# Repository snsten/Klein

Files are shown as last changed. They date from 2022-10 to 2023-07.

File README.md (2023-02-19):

# Klein Keyboard

Klein keyboard is a 36 keys, columnar staggered, split keyboard named after [Felix Klein](https://en.wikipedia.org/wiki/Felix_Klein)

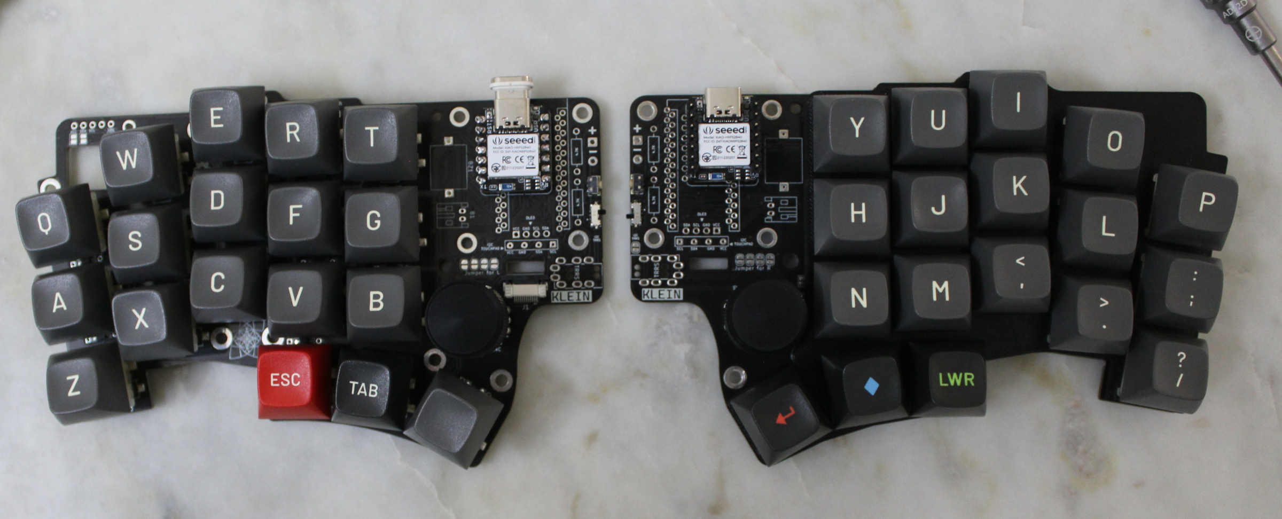
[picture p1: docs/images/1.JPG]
Klein


---

## Features

- Column Staggered
- Bluetooth compatible with power switch
- Seeed Studio XIAO-BLE / Pro Micro / nice!nano\* / KB2040 / RP2040(boards with Pro Micro pinout) compatible
- Hotswap MX and Choc switches support
- Trackpad support with FPC cable and direct wiring
- Reversible SMD and through hole diode footprint

> \* nice!nano firmware not available at the moment.

## Versions

Supports multiple options of micro controller and sensors.

| Features Supported | Microcontroller | Firmware available | Wired | Wireless |
| --- | --- | --- | ----- | --- |
| Encoder or OLED | XIAO-BLE | [Yes](https://github.com/snsten/Klein-zmk) | | Yes |
| Encoder, OLED, TouchPad, Buzzer, Haptics | Pro Micro | [Yes](https://github.com/snsten/Klein-qmk) | Yes | |
| Encoder, OLED, TouchPad, Buzzer, Haptics | KB2040/RP2040 | [Yes](https://github.com/snsten/Klein-qmk) | Yes | |
| Encoder and OLED | nice!nano | No (Planned) | | Yes |

Broadly divided in two types:

### Wireless

- Can be made with Seeed Studio XIAO-BLE
- Supports either rotary encoder or OLED
- Battery connectors JST and THT

Wireless touchpad is currently not supported in ZMK.

### Wired

- With any Pro Micro based boards
  - Can support encoders, OLED, Touchpad, Buzzer and Haptics

---

### Keyboard Images

PCB with both Choc and MX switches
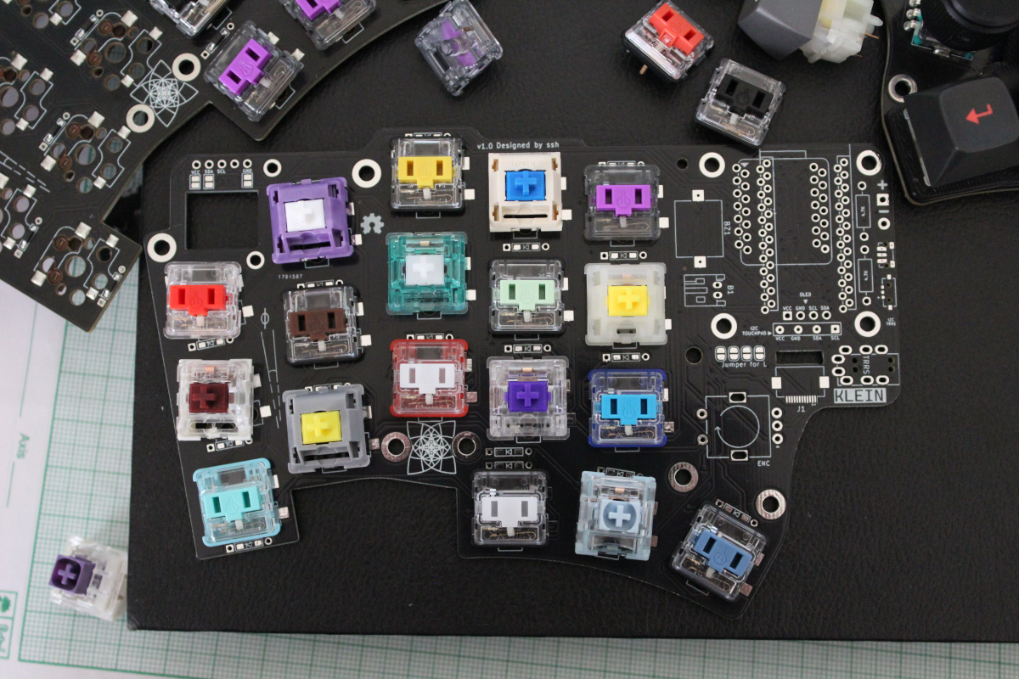
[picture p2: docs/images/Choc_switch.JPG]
Klein Choc Switches


Low Profile Choc version
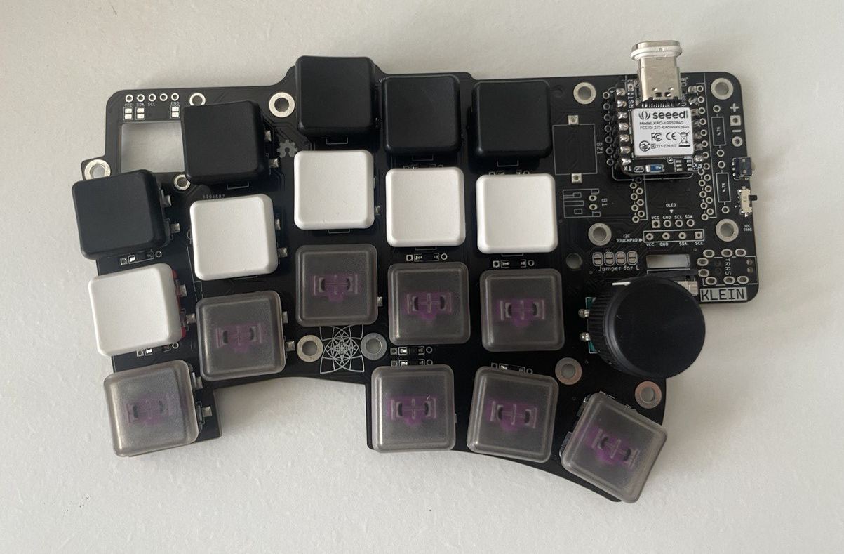
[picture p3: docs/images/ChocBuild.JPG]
Klein MX Choc Switches


MX version
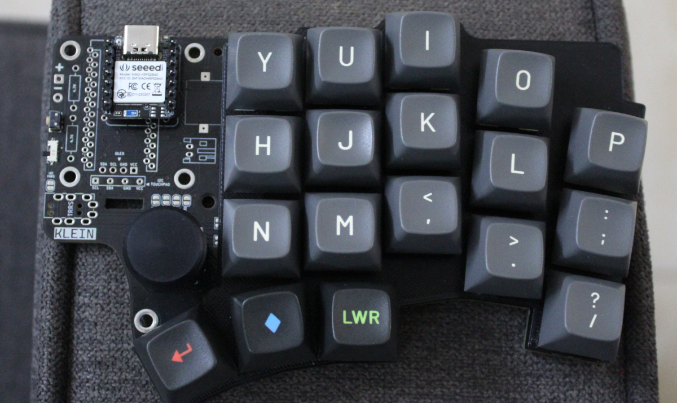
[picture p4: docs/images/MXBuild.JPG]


---

## Repo Layout and Files

```
.
├── BOM
│   ├── BOM-3235-SEEED.csv         <- BOM
│   └── ibom.html
├── Case
│   └── *.stl                      <- Case stl Files
│   └── Prototype                  <- FreeCad project files (Not tested)
│       └── SwitchPlateFR4         <- SwitchPlate PCB files (Not tested)
├── docs
│   └── images
├── Logo
├── PCB
└── README.md
```

## BOM

It is available in BOM directory as csv file and [interactive HTML BOM](https://htmlpreview.github.io/?https://github.com/snsten/Klein/blob/main/BOM/ibom.html)

## Build Guide

- Wired build [guide](https://github.com/snsten/Klein/blob/main/docs/buildguides/buildguide_wired.md)
- Wireless build [guide](https://github.com/snsten/Klein/blob/main/docs/buildguides/buildguide_wireless.md)

## Todo

- Add Build Guide
- Add Touchpad related 3D Models
- Software support for Touchpad/OLED

## Firmware

- [ZMK shield](https://github.com/snsten/Klein-zmk) for Klein with rotary encoder support.
- [QMK Firmware](https://github.com/snsten/Klein-qmk) for Pro Micro with touchpad support.

## Refrences

These projects inspired and helped in making Klein:

- [Lily58](https://github.com/kata0510/Lily58) (Hotswap Footprints)
- [Dilemma](https://github.com/Bastardkb/dilemma) (Trackpad Mount, Design)
- [KLOR](https://github.com/GEIGEIGEIST/KLOR) (Haptics Footprints, Design)
- [Claw44](https://github.com/yfuku/claw44) (Design)

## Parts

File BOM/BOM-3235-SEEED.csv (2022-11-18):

Designator | MPN/Seeed SKU | Qty | Link
D1, D2, D3, D4, D5, D6, D7, D8, D9, D10, D11, D12, D13, D14, D15, D16, D17, D18, D19 | 1N4148W | 19 | https://file.elecfans.com/web1/M00/9B/4F/o4YBAF0kaAOAOa7_AAPvYDJhMOM395.pdf?filename=1N4148W.pdf
M1 | 102010448 | 1 | https://statics3.seeedstudio.com/fusion/opl/datasheet/102010448.pdf
B1 | S2B-PH-K-S(LF)(SN) | 1 | https://file.elecfans.com/web1/M00/56/28/pIYBAFs5_uCAdW0LAAHQrBga-SA964.pdf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
S1 | SSAJ110100 | 1 | https://file.elecfans.com/web1/M00/B8/ED/o4YBAF6BmECACKjzAAnBvSqgQfU963.pdf?filename=SSAJ110100-ALPS.pdf
S16 | EC11E18244AU | 1 | https://file.elecfans.com/web1/M00/90/2D/o4YBAFzFBtCALQJ0AAlE9NU9dVE732.pdf?filename=EC11E18244AU_ALPS.pdf
H1, H2, H3, H4, H5, H6 | 326010010 | 6 | https://statics3.seeedstudio.com/fusion/opl/datasheet/326010010.pdf
U1 | 326010014 | 4 | https://statics3.seeedstudio.com/fusion/opl/datasheet/326010014.pdf
RSW1 | SKRTLAE010 | 1 | https://file.elecfans.com/web1/M00/8E/E1/o4YBAFy5PDeAGPVcAAin-c8L2b4965.pdf?filename=SKRTLAE010_ALPS.pdf
J1 | AFC07-S12FCA-00 | 1 | https://file.elecfans.com/web1/M00/86/24/o4YBAFx8f7-AXpwqAAO6FXDMfQQ684.pdf
BZ1 | AST1109MLTRQ | 1 | https://www.mouser.com/ProductDetail/Mallory-Sonalert/AST1109MLTRQ?qs=GpRChIzryBM5c7g4uet5pQ%3D%3D
J2 | PIM452 | 1 | https://www.mouser.com/ProductDetail/Pimoroni/PIM452?qs=PzGy0jfpSMsfx56IL0dynA%3D%3D
R1, R2 | MF1/4LCT52R472J | 2 | https://www.mouser.com/ProductDetail/KOA-Speer/MF1-4LCT52R472J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

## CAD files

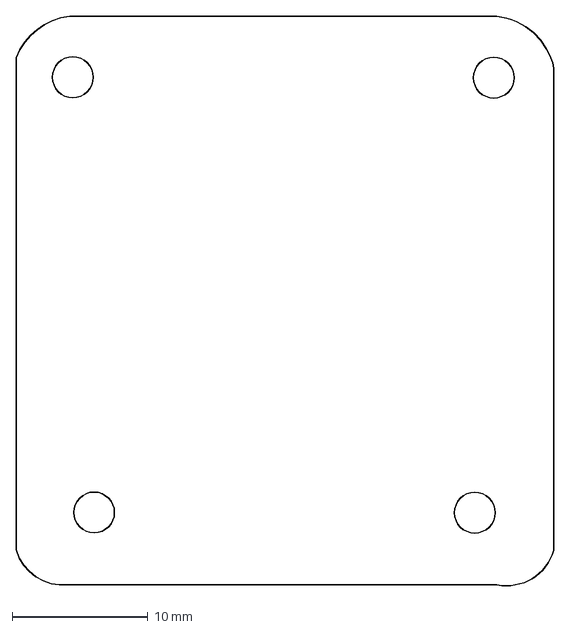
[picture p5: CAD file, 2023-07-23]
Case/coverPlate.dxf
39.5 x 42.2 mm

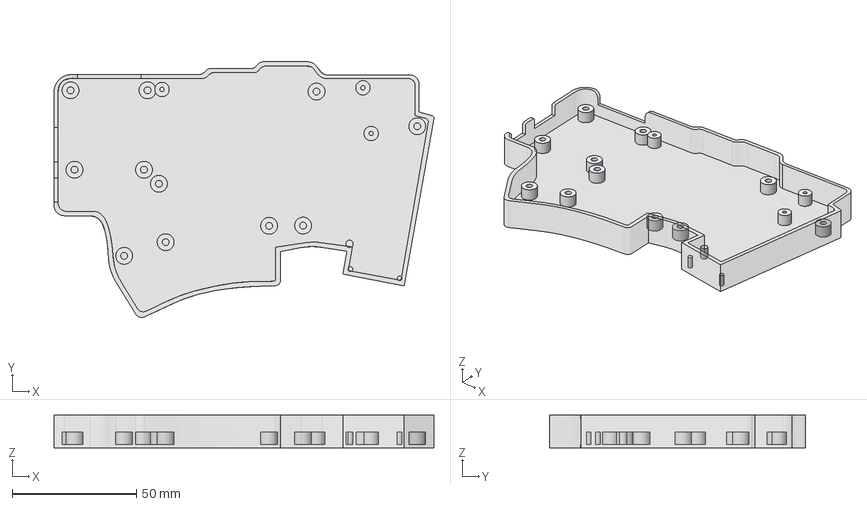
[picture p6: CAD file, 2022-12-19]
Case/Prototype/Wired_Prototype.FCStd
153.1 x 103.1 x 13.2 mm
Case
M2Hole
M2Hole001
M2Hole002
M3Hole
M3Hole001
M3Hole002
M3Hole003
M3Hole004
M3Hole005
M3Hole006
M3Hole007
M3Hole008
M3Hole009
M3Hole010
SupportCol
SupportCol001
SupportCol002

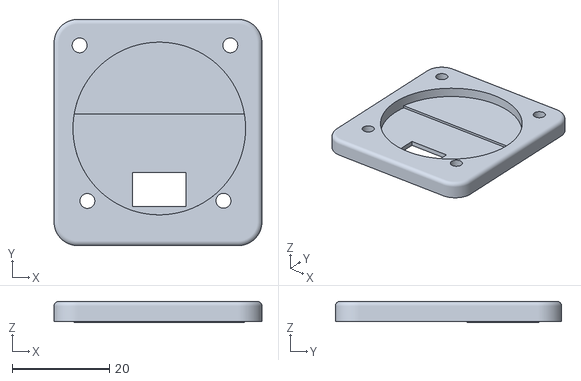
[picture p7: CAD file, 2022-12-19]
Case/TrackPadMount.stl
42.8 x 46.5 x 4.40

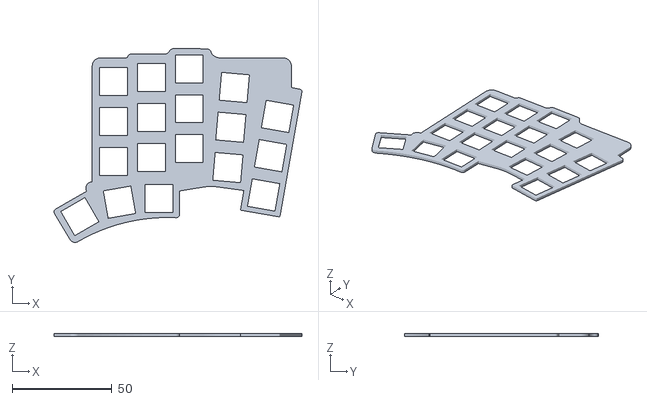
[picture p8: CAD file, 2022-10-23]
Case/Klein-switchplate.stl
124.4 x 97.2 x 1.60

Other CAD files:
Case/KleinCase-R.stl

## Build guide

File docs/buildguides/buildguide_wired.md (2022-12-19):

# Klein Wired Build Guide

---

## Table of contents

- [Overview](#overview)
- [Version Info](#version-info)
- [Parts List](#parts-list)
- [Tools Required](#tools-required)
- [Tutorials](#tutorials)
- [Build Steps](#build-steps)
  - [Diodes](#diodes)
  - [Switch Sockets](#switch-sockets)
  - [Microcontroller](#microcontroller)
  - [TRRS](#TRRS)
- [Optional](#optional)
  - [Rotary Encoders](#rotary-encoder)
  - [OLED](#oled)
  - [Trackpad](#trackpad)
  - [Reset Switch](#reset-switch)
- [Assembly](#assembly)
  - [SwitchPlate](#switchplate)
  - [Case assembly](#case-assembly)
  - [Firmware](#firmware)
- [TODO](#todo)

---

## Overview

PCB Layout and orientation

### Front / Right Side of PCB

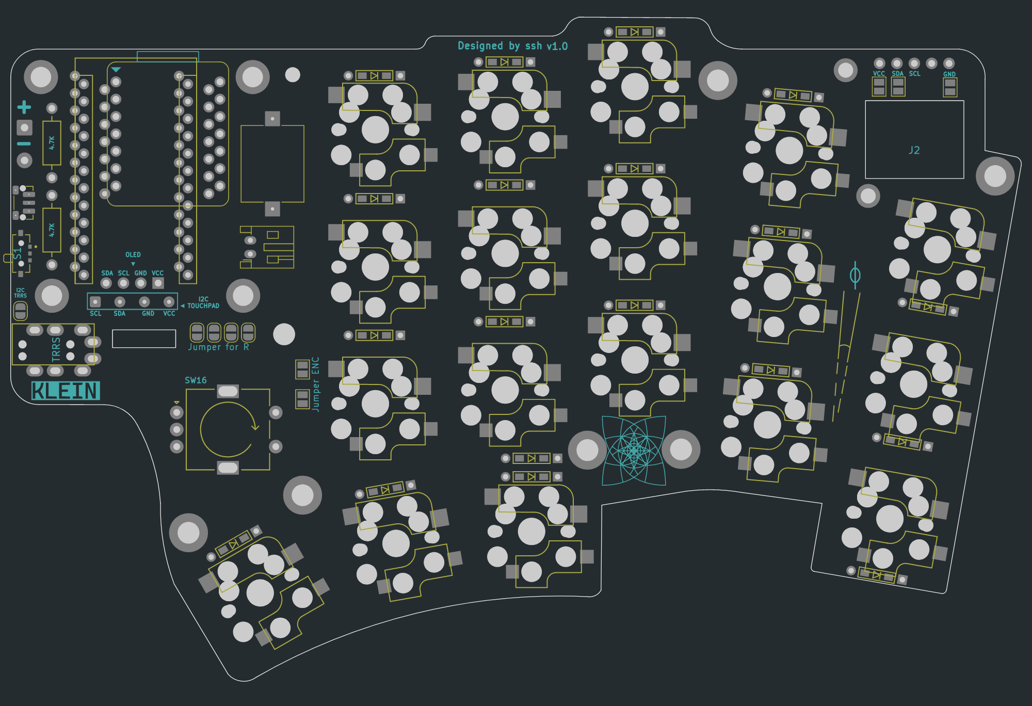
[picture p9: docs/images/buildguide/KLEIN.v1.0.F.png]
Klein Front


### Back / Left Side of PCB

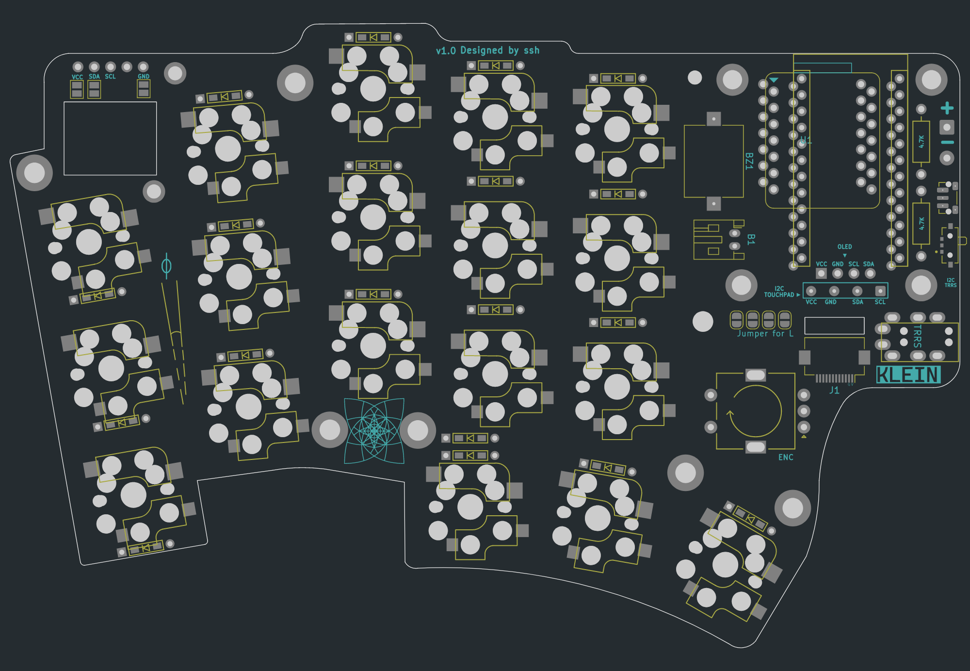
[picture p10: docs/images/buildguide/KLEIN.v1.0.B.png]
Klein Back


## Version Info

- Wired version works with Pro Micro and KB2040.
- Should work with other RP2040 boards with minor modifications to firmware.
- The KB2040 firmware doesn't support Audio Buzzer.

## Parts List

See [BOM](https://github.com/snsten/Klein/tree/main/BOM) directory

## Tools Required

- Soldering Station / Iron
- Electrical Wire Nipper (Useful to cut diode/resistor legs)
- Precision Tweezer like [these](https://en.goot.jp/products/detail/ts_15) (For SMD diode/switches placement)
- Masking Tape to hold components in place while soldering
- Optional Flux for Trackpad connector

## Tutorials

There are lot of soldering tutorials available online.
For SMD parts I recommend [this](https://www.youtube.com/watch?v=hoLf8gvvXXU).

For socketing of microcontroller see the guides at [40percent.club](https://www.40percent.club/p/socketing-pro-micro.html) or [splitkb docs](https://docs.splitkb.com/hc/en-us/articles/360011263059).

For prepration of Trackpad see this guide at [ Keycapsss](https://github.com/Keycapsss/cirque-trackpad) or [beekeeb](https://beekeeb.com/cirque-trackpad-i2c-on-corne-keyboard/).

---

## Build Steps

### Diodes

Diode are placed on the same side of PCB as hotswap sockets.

Throughole or SMD type diodes can be used. Diodes are polarized so keep the direction in mind.

| Diode symbols | Diode symbols on IBOM and the PCB | SMD Diode in SOD 123 package | Through Hole Diode |
| :---: | :---: | :---: | :---: |
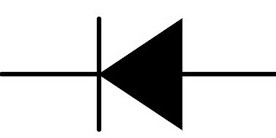
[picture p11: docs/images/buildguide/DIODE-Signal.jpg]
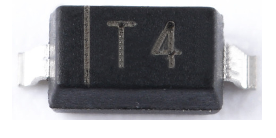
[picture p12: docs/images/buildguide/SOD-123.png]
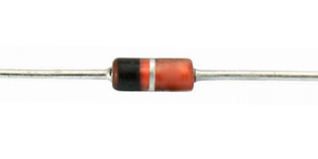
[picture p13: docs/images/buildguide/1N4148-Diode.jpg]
|  |   |  |  |

Using the line match the symbol with the actual diode before soldering.

| Tin the Diode Pads | Reheat the pads to solder the Diodes |
| :---: | :---: |
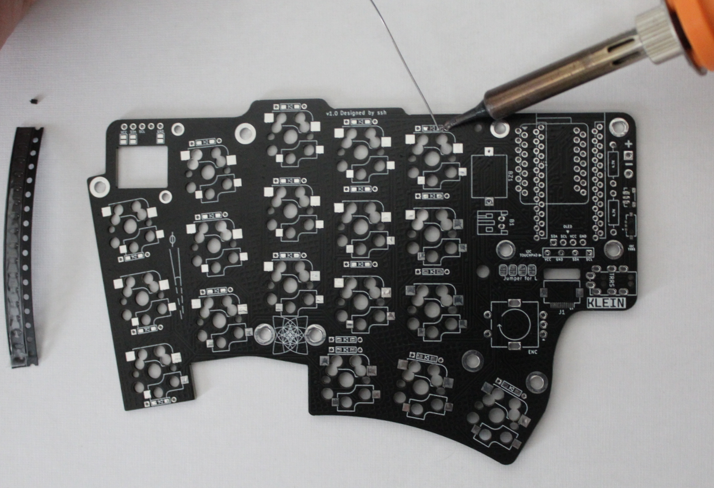
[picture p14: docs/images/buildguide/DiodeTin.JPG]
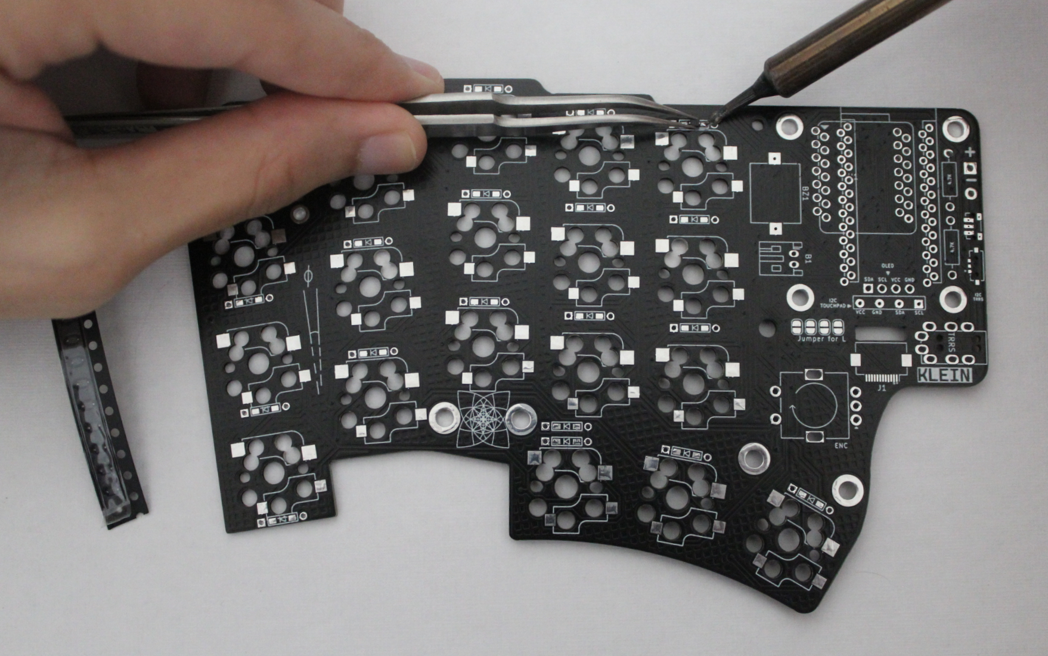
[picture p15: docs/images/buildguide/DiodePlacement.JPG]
|  |  |

---

### Switch Sockets

Either MX, Choc or both compatible sockets can be used.
You can tin the pads with solder and then reheat to connect the sockets.
Or you can heat the socket, pad directly and solder.

| Tin the Socket Pads |  Reheat the pads to solder the Sockets  |
| :---: | :---: |
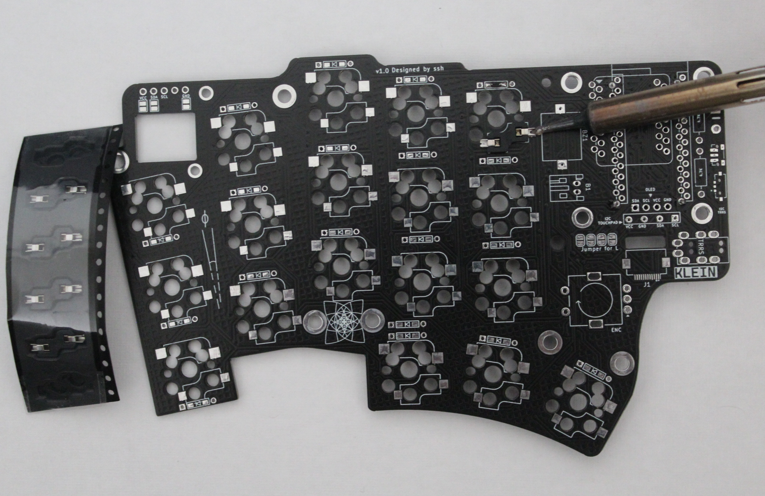
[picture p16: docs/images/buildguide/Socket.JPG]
|  |  |

---

### Microcontroller

- It is recommended to socket your microcontroller.
- The microcontroller position for Pro Micro is marked on the PCB as enclosed box.

  | Prepare the IC socket by cutting top part  |   Use Masking Tape to fix the socket in Place   |         Solder all the pins of the socket         |
  | :----------------------------------------: | :---------------------------------------------: | :-----------------------------------------------: |
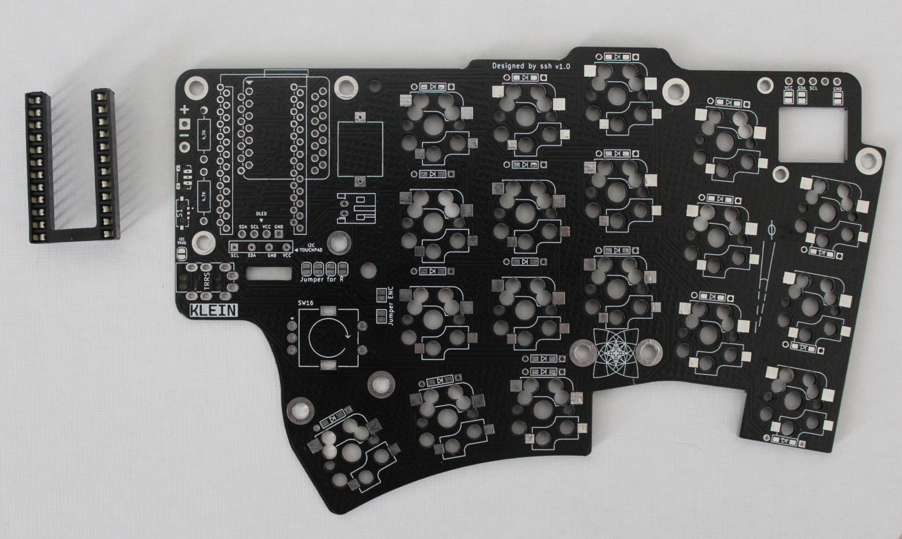
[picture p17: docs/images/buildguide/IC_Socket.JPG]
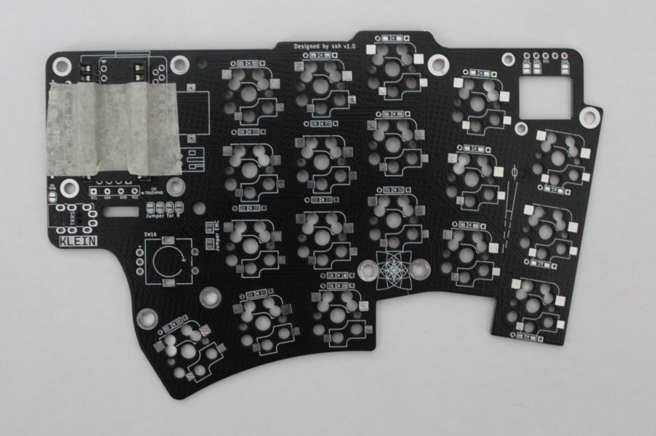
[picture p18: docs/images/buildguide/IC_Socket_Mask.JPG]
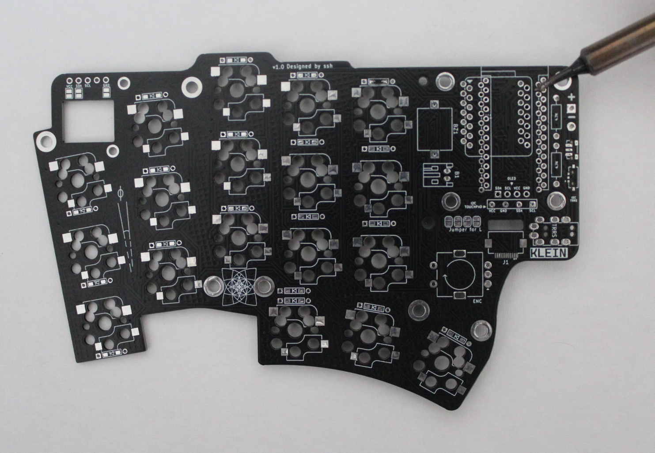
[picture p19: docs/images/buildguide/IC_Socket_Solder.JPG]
  |  |  |  |

- Do the same for left side keeping the PIN orientation in check.

---

### TRRS

Note: To connect the two halves use 4-pole TRRS and not the 3-pole TRS cable. TRS cable is not supported and could damage the keyboard.

| Bridge the TRRS Jumper | Using tweezer bend the TRRS Jack pins as the second jack as shown in image |
| :---: | :---: |
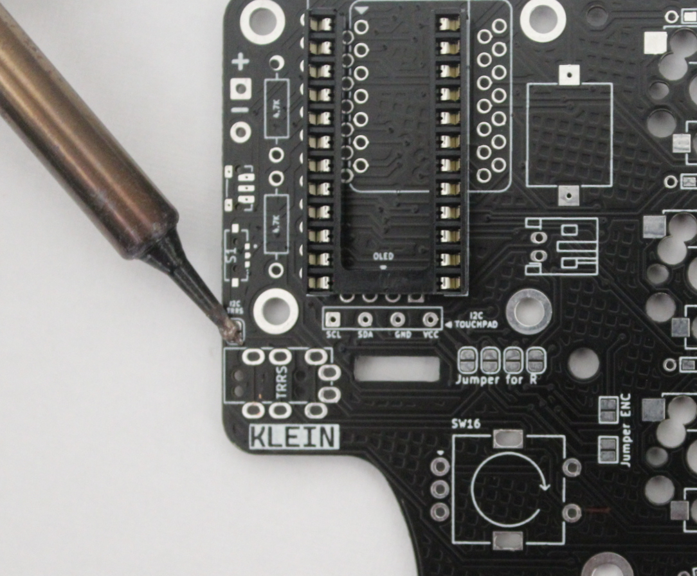
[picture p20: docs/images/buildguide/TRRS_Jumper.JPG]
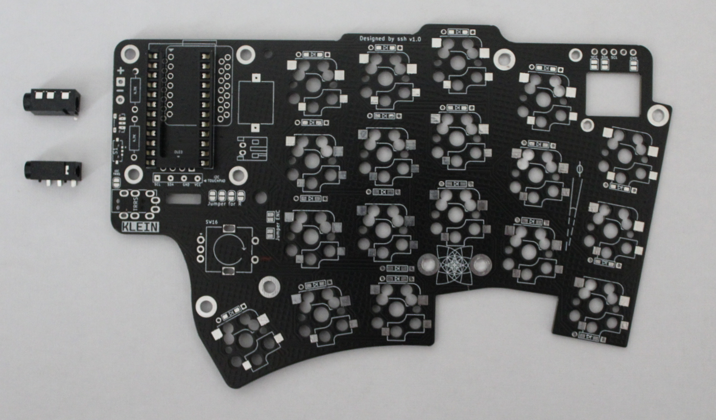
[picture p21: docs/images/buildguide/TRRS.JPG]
|  |  |

TRRS Jack used is a surface mounted component but we will solder it as through hole.

| Place the TRRS Jack matching pins on the PCB |  Use Masking Tape to fix the jack in place  | Solder the 4 pins of the jack |
| :---: | :---: | :---: |
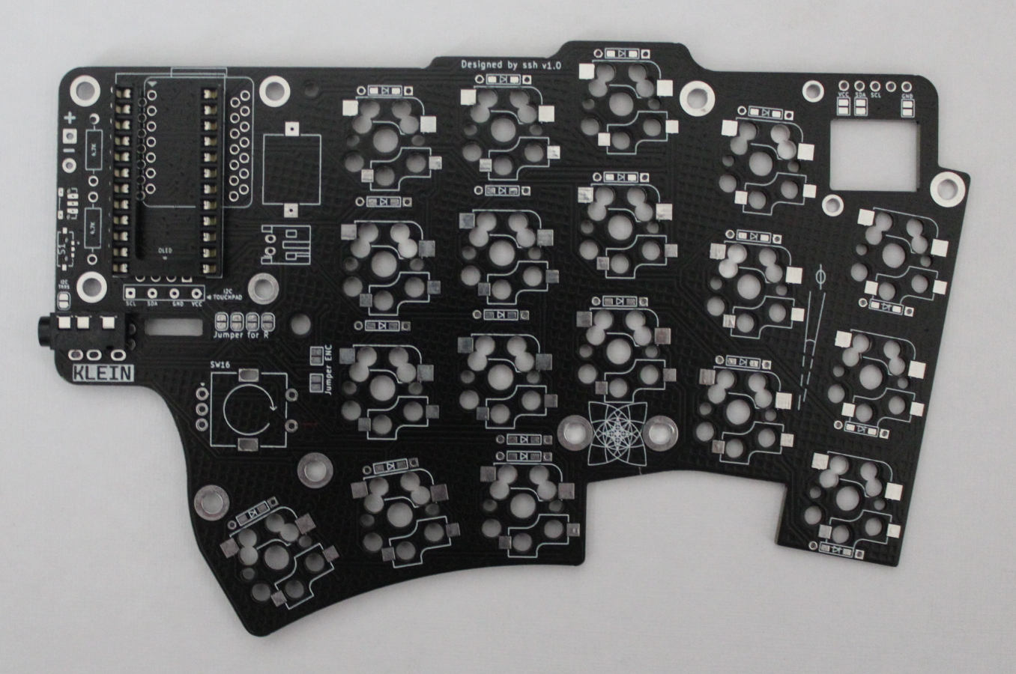
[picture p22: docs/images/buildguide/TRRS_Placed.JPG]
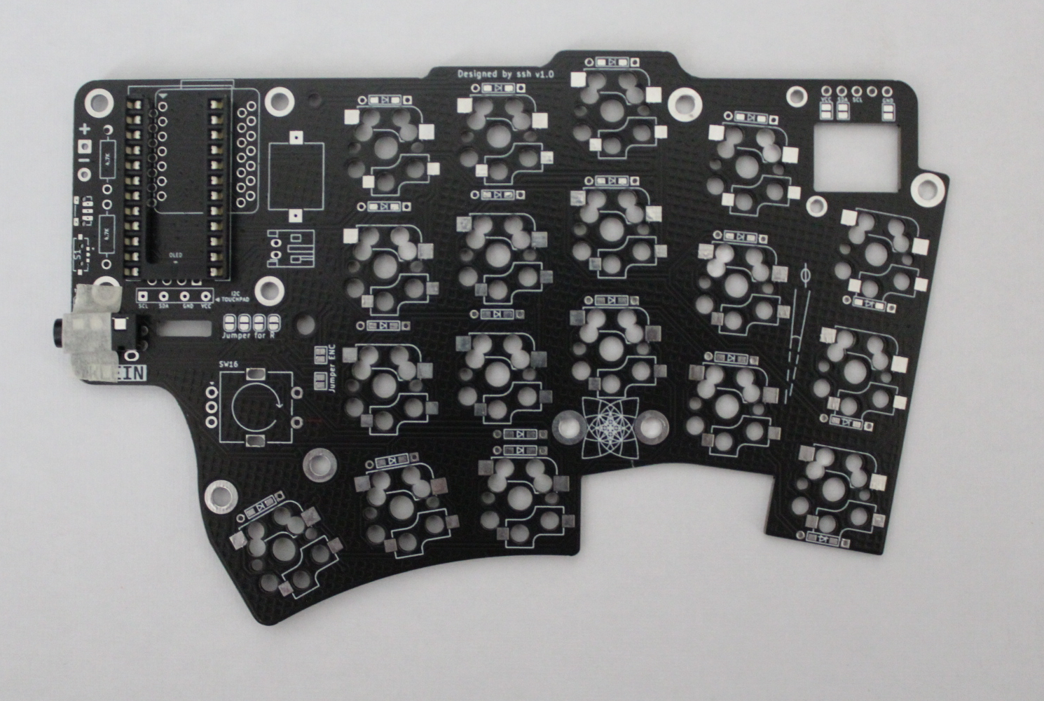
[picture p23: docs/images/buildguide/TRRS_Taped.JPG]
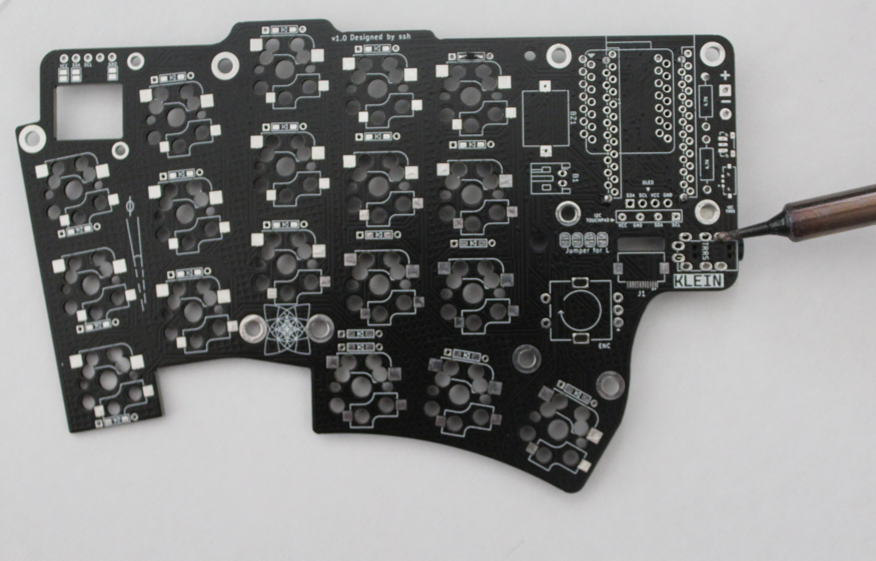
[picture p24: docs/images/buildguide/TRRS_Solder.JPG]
|  |  |  |

- Do the same for left side keeping the PIN orientation in check.

---

## Optional

### Rotary Encoders

If you use MX or Choc choose rotary encoder based on the height:

- For MX with MT3/SA profile you can use the encoder specified in BOM which has an actuator length of 20mm.
- For Choc or MX with medium/low profile keycaps something like EC11N1524402 or similar which have actuator length of 15mm will be better.
- EC12 can also be used without the switch functionality.

This is personal preference so any option is fine.

| Prepare the Encoder | Carefully place the Encoder | Solder the 2 big mounting pins first then the rest of pins |
| :---: | :---: | :---: |
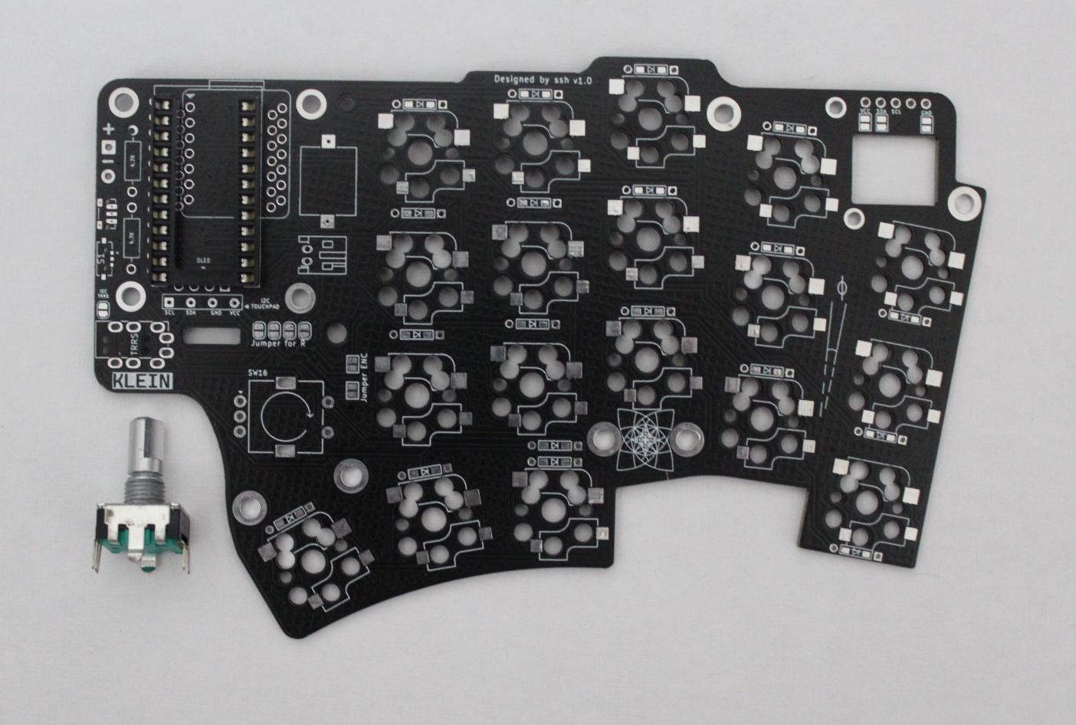
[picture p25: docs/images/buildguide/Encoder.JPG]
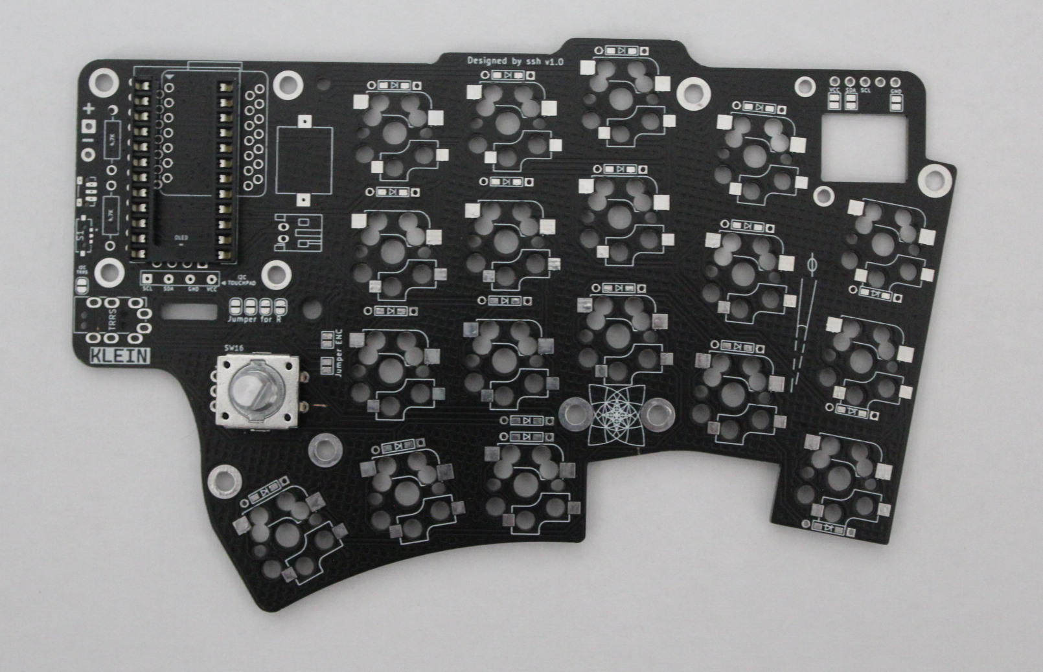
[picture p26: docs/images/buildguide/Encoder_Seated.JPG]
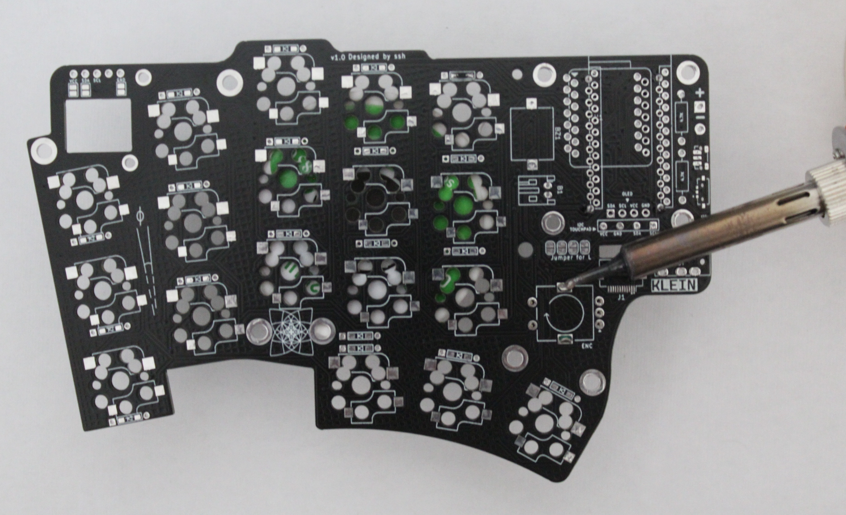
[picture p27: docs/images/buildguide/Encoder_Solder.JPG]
|  |  |  |

---

### OLED

Note: OLED has some clearance issue with pro micro sockets. You can check by placing the sockets and OLED before soldering to confirm. Will be fixed in next revision.

It is required to bridge the Jumpers if you want to use the Oled display.

Bridge the 4 jumper labelled "Jumper for L/R" for Left and Right hand respectively at the position in shown in image. [](https://htmlpreview.github.io/?https://github.com/snsten/Klein/blob/main/BOM/ibom.html)

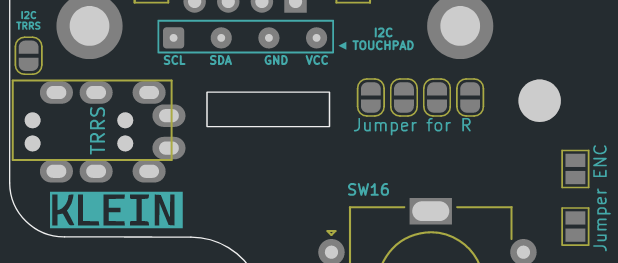
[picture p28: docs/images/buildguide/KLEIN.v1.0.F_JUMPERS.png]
Jumpers


---

### Trackpad

Not the easiest part to solder, try to use <= 0.5 mm solder wire along with a pointed tip or small chiesel tip for drag soldering.
Use lots of flux and avoid bridging between pins.

Use a multimeter to check if all connections are working and there is no short between adjacent pins.

#### Trackpad Modification

- Desolder/Remove R1 as it is required for I2C communiaction.
- If you are using Pro Micro remove R7 and R8 as well. If your microcontroller(like KB2040) can provide 3.3V then it is not required.
- Alternatively you can cut off these resistor with electric nippers.
- Be careful not to remove adjacent components.

  | Trackpad resistors to remove. Image from guide by [ Keycapsss](https://github.com/Keycapsss/cirque-trackpad). |
  | :-----------------------------------------------------------------------------------------------------------: |
  |              |

  Add two pull up resistor of 4.7K ohms, orientation doesn't matter with resistors.

  |     Add two 4.7K resistor at position shown in IBOM     |                  Two 4.7K resistor soldered on PCB |
  | :-----------------------------------------------------: | -------------------------------------------------: |
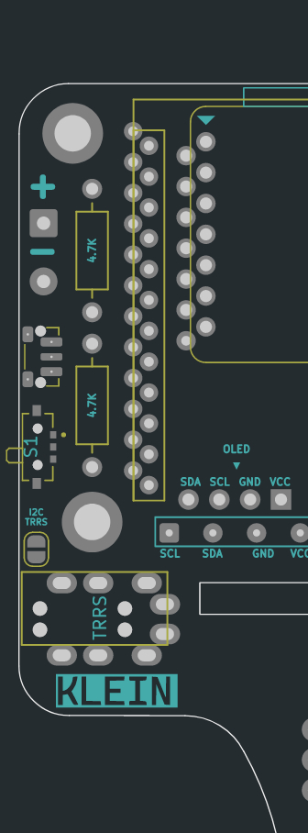
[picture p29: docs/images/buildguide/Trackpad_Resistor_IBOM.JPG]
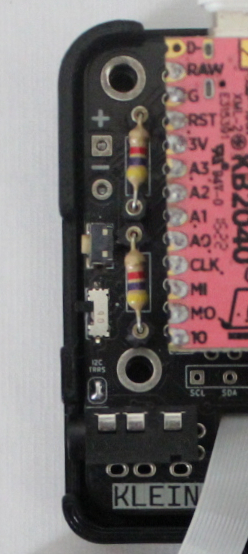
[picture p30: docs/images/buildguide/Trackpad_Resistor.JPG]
  |  |  |

#### Soldering the FPC connector.

| Tin the pads of FPC connector J1 on PCB  | Use tape to fix the FPC connector and solder each pin | The ribbon cable can be connected by pulling the notch | Close it by pushing the notch |
| :---: | :---: | :---: | :---: |
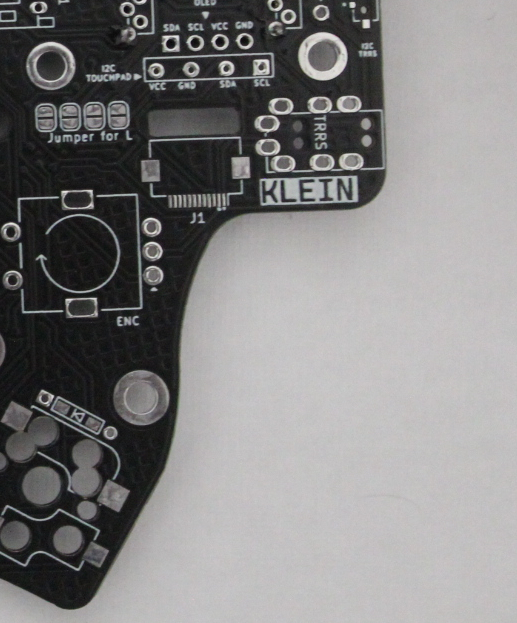
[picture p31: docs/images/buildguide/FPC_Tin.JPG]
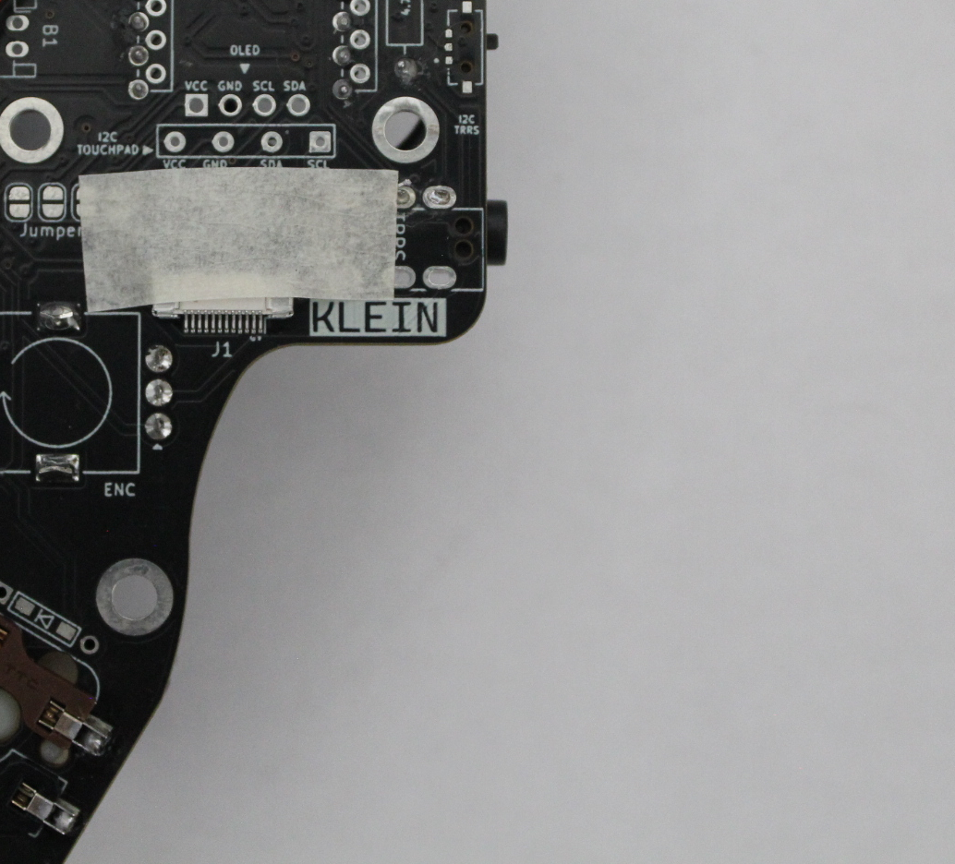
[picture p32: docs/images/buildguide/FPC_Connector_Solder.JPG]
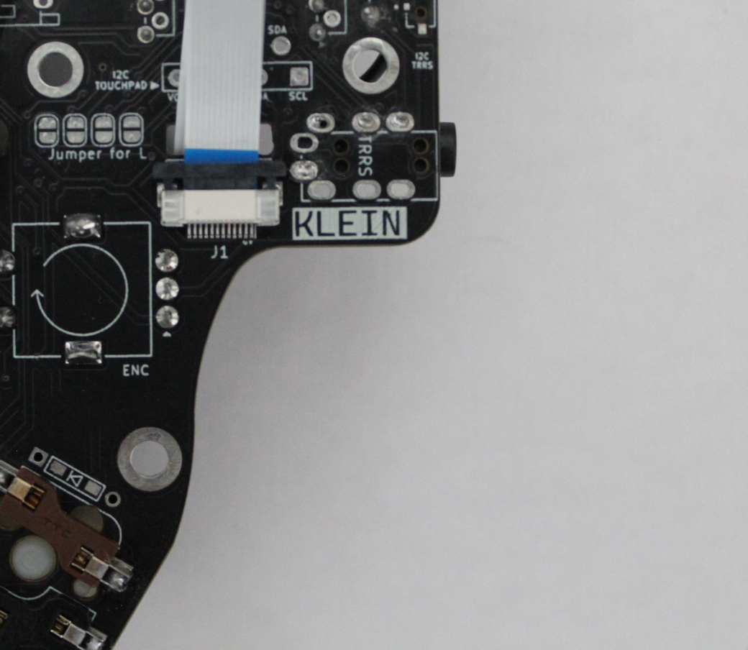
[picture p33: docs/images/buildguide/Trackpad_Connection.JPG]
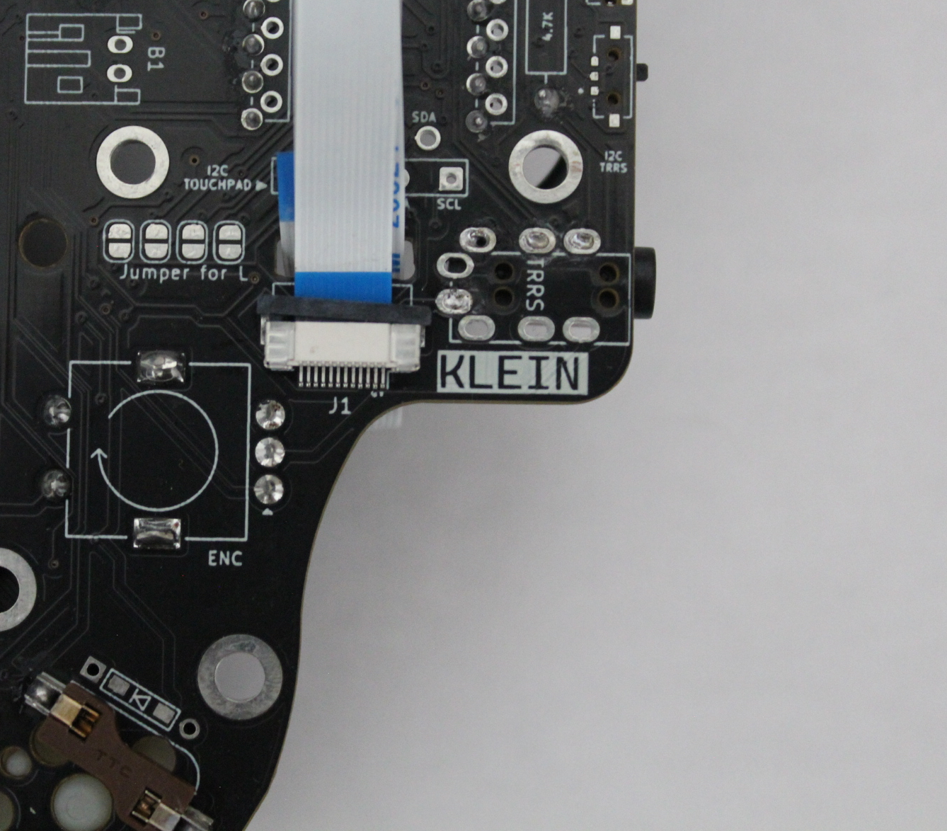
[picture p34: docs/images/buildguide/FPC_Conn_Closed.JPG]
|  |  |    |  |

#### Trackpad Assembly

| Use Double Sided Tape on the lower half of the Trackpad | Carefully place the Trackpad in the assembly using double sided tape | Connect the ribbon cable from previos step with the assembly |
| :---: | :---: | :---: |
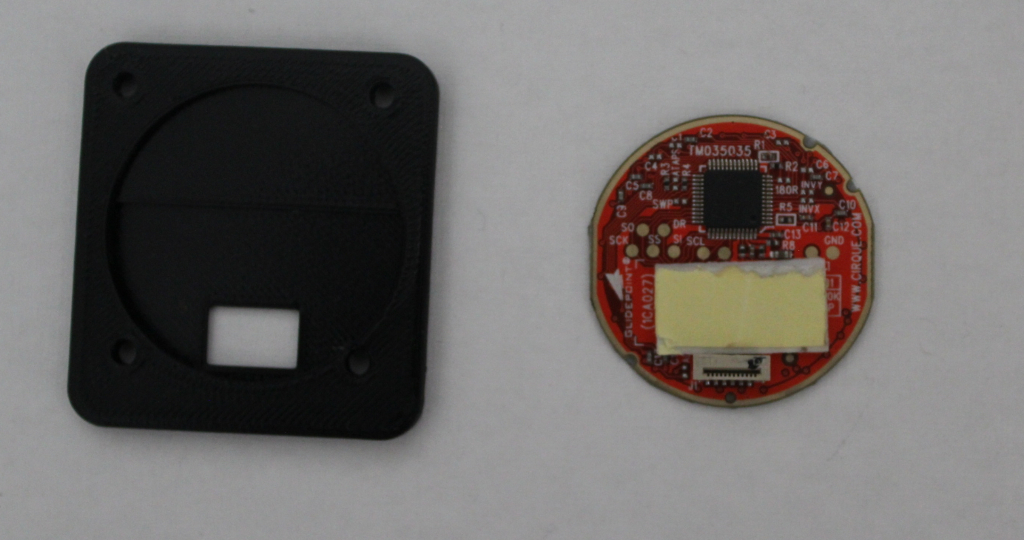
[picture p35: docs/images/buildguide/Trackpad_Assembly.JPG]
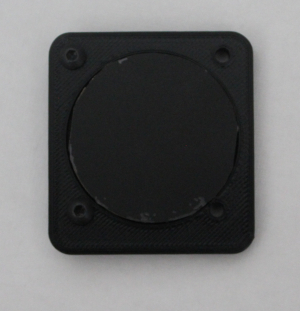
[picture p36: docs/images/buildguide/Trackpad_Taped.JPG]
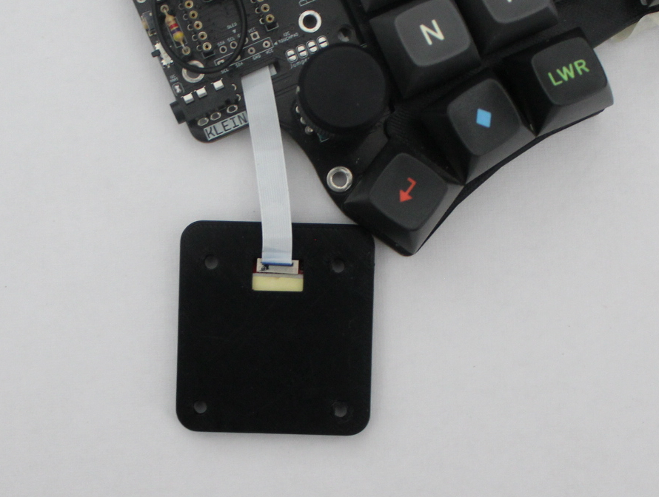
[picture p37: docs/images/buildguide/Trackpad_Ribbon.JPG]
|  |  |  |

| Trackpad Assembly will fit on PCB using 4x M3 10mm Standoff and 3x M3 5mm screws | Use M3 standoff in 4 corners as shown below | Place the trackpad mount on top of standoff and use screws to fix it |
| :---: | :---: | :---: |
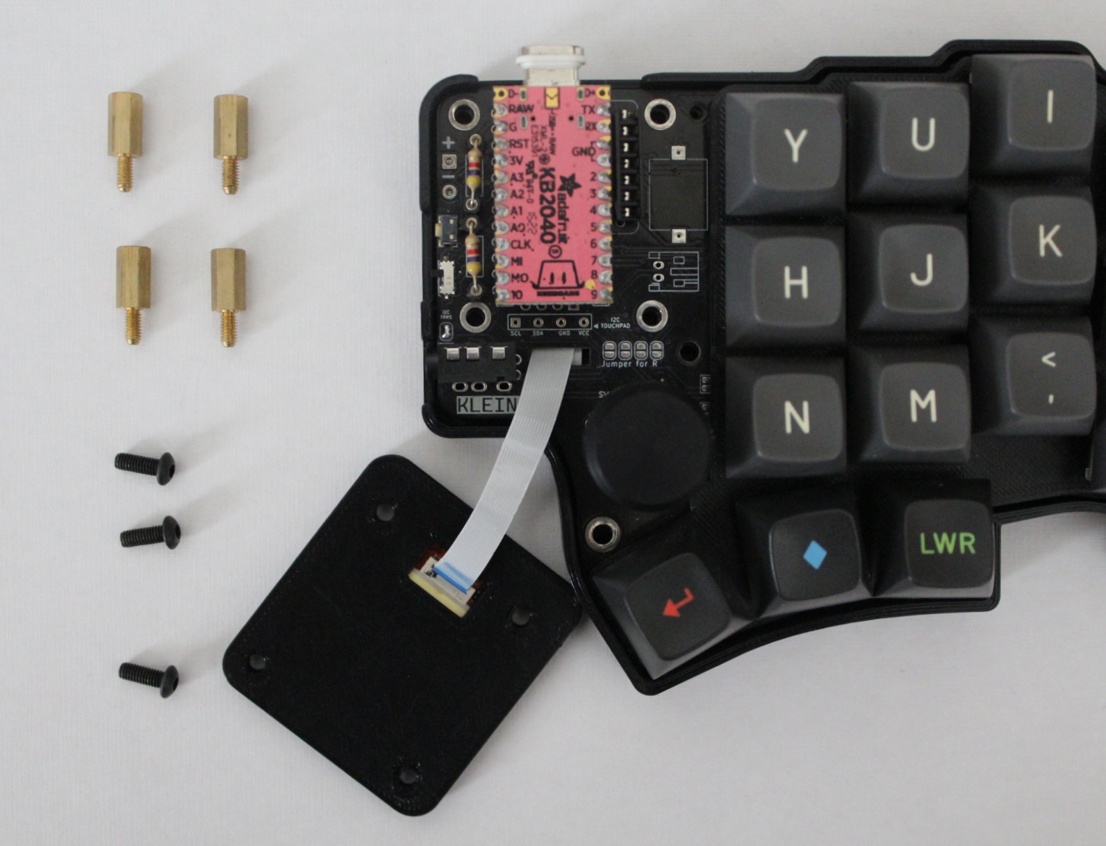
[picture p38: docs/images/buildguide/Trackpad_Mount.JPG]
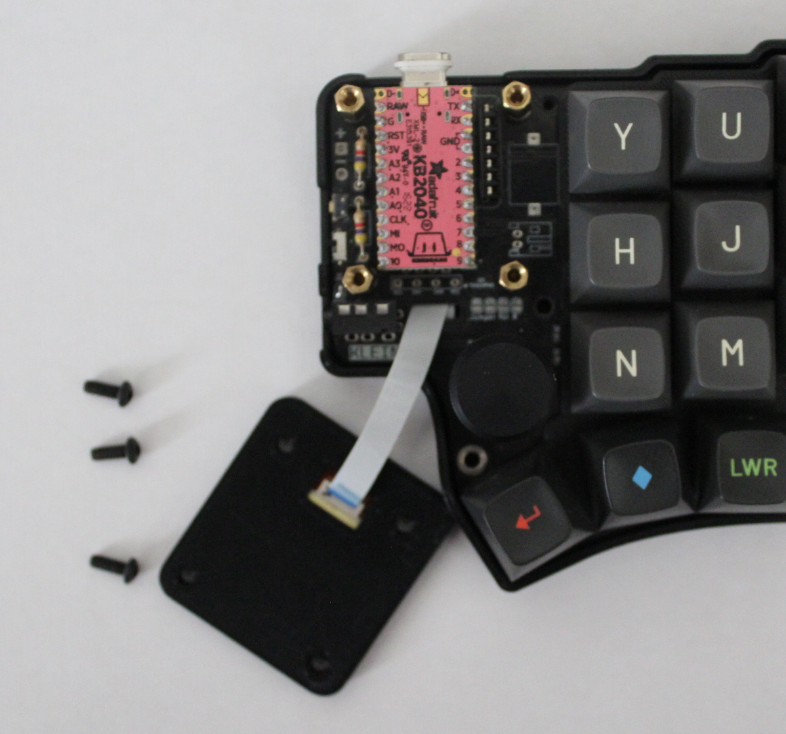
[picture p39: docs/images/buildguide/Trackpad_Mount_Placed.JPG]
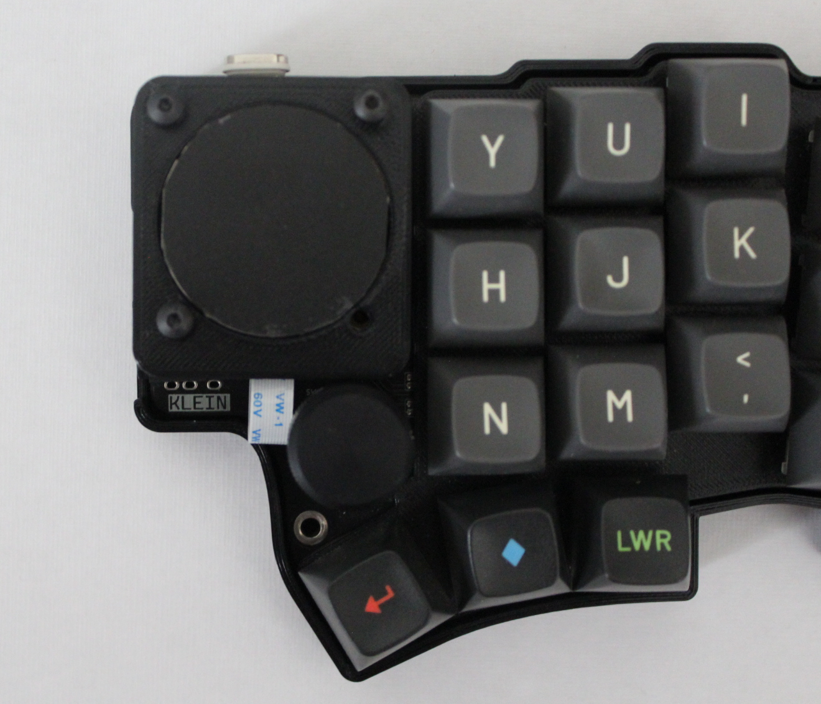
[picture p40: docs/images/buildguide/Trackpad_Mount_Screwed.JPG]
|  |  |  |

Fourth screw is not required as it will interfere with trackpad scroll action.

---

### Reset Switch

Tin the pads with some solder and the solder the Reset Switch by the side pads first and then the main connections using generous amounts of flux.

---

## Assembly

### Switchplate, Switches and Keycaps

Switchplates are avialable in case directory in [repo](https://github.com/snsten/Klein/tree/main/Case).

Insert few switches in switchplate then gently place it on top of PCB aligning with the hotswap sockets.

Place rest of the switches one by one on switchplate without applying too much force.

After all the switches are placed you can place the keycaps on top of them.

### Case assembly

Case files are available [here](https://github.com/snsten/Klein/tree/main/Case).

### Firmware

The firmware is available [here](https://github.com/snsten/Klein-qmk).

---

## TODO

&#9744; Add detailed parts list

&#9744; Add images for rest of the steps

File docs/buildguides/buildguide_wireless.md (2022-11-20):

# Klein Wireless Build Guide

---

## Table of contents

- [Overview](#overview)
- [Version Info](#version-info)
- [Parts List](#parts-list)
- [Tools Required](#tools-required)
- [Tutorials](#tutorials)
- [Build Steps](#build-steps)
  - [Diodes](#diy-version)
  - [Switch Sockets](#switch-sockets)
  - [Battery](#battery)
  - [Microcontroller](#microcontroller)
  - [Optional](#optional)
    - [Power Switch](#power-switch)
    - [Reset Switch](#reset-switch)
    - [Jumpers](#jumpers)
    - [Rotary Encoders](#rotary-encoder)
  - [SwitchPlate](#switchplate)
  - [Case assembly](#case-assembly)
  - [Firmware](#firmware)
- [TODO](#todo)

---

## Overview

PCB Layout and orientation

### Front / Right Side of PCB

Klein Front

### Back / Left Side of PCB

Klein Back

## Version Info

- Currently the wireless version is tested with XIAO-BLE only.
- Should work with nice!nano but haven't tested and implemented in ZMK yet.
- The wireless version doesn't support Trackpad, Haptics or Buzzer.

## Parts List

See [BOM](https://github.com/snsten/Klein/tree/main/BOM) directory

## Tools Required

- Soldering Station / Iron
- Electrical Wire Nipper (Useful to cut diode/resistor legs)
- Precision Tweezer like [these](https://en.goot.jp/products/detail/ts_15) (For SMD diode/switches placement)
- Masking Tape to hold components in place while soldering

## Tutorials

There are lot of soldering tutorials available online. For SMD parts I recommend [this](https://www.youtube.com/watch?v=hoLf8gvvXXU).

For socketing of microcontroller see the guides at [40percent.club](https://www.40percent.club/p/socketing-pro-micro.html) or [splitkb docs](https://docs.splitkb.com/hc/en-us/articles/360011263059).

---

## Build Steps

### Diodes

Diode should be placed on the same side of PCB as switches and opposite side of hotswap sockets.

Throughole or SMD type diodes can be used. Diodes are polarized so keep the direction in mind.

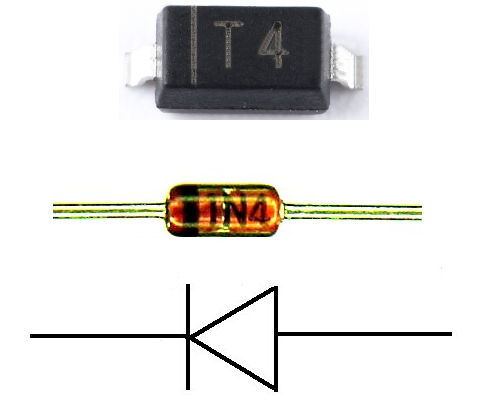
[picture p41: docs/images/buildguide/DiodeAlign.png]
Types of Diode


Using the line match the symbol with the actual diode before soldering.

DIODE SYMBOL

### Switch Sockets

Either MX, Choc or both compatible sockets can be used.
You can tin the pads with solder and then reheat to connect the sockets.
Or you can heat the socket, pad directly and solder.

### Battery

The battery can be any 3.7V lipo like [these](https://www.lipobattery.us/tag/thickness-3mm/) keeping dimension and capacity in mind.

- Don't get anything with depth 4mm or above as they will be hard to fit.
- Tested with battery dimensions 26x10x3.5 mm and 200mAh capacity which fit below pcb or microcontroller.

You can connect battery directly to the +/- terminal on XIAO-BLE +/- pad, this method will bypass the switch.

or

Solder the female JST plug at position B1 see in [ibom](https://htmlpreview.github.io/?https://github.com/snsten/Klein/blob/main/BOM/ibom.html) on the PCB.

- Attach the Battery using JST connector.

### Microcontroller

- It is recommended to socket your microcontroller.
- The microcontroller position for XIAO is marked by the inverted triangle on PCB.

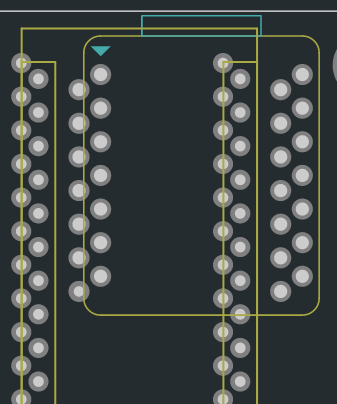
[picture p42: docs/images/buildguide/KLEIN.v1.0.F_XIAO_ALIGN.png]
XIAO SYMBOL
  

- For battery connection you need to solder wire from +PAD on XIAO-BLE to any of the 2 BAT+ pins marked with red box shown below.

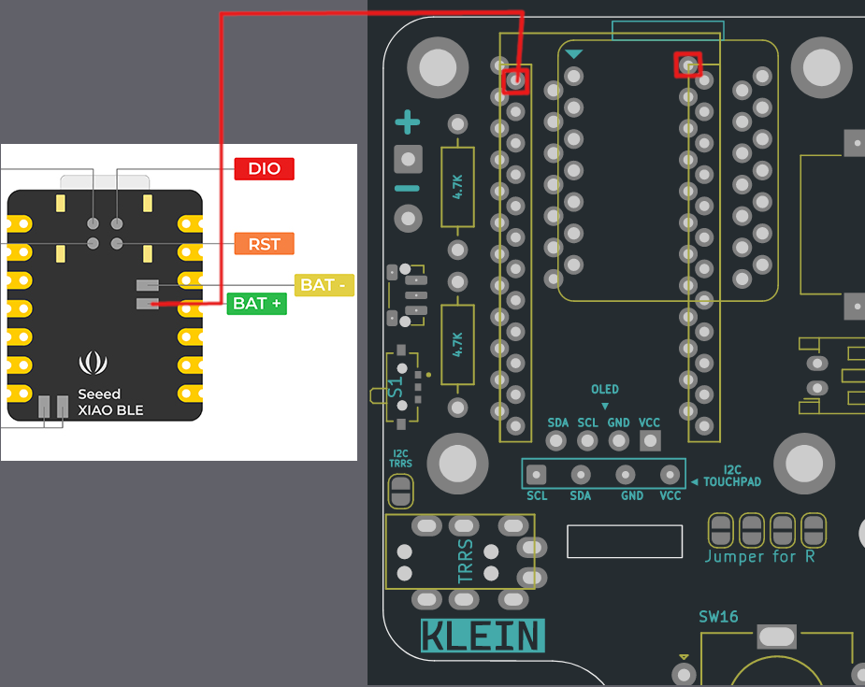
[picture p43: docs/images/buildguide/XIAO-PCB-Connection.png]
XIAO-PCB-Connection
  

- Do the same for left side keeping the PIN orientation in check.

### Optional

#### Power Switch

Tin the pads with some solder and then solder the Power Switch by the side pads first and then the main connections using generous amounts of flux.

#### Reset Switch

Reset switch is for only Pro Micro footprint boards. If you want to make it work with XIAO another connection like the BAT+ has to be made from XIAO reset pad to RESET PINS on pro micro footprint.

Tin the pads with some solder and the solder the Reset Switch by the side pads first and then the main connections using generous amounts of flux.

#### Jumpers

Jumpers is required if you want to use

- Rotary encoder then bridge 2 ENC jumper at postion JP9, JP10 see [ibom](https://htmlpreview.github.io/?https://github.com/snsten/Klein/blob/main/BOM/ibom.html).
- Oled display then bridge 4 jumper for L/R at position see [ibom](https://htmlpreview.github.io/?https://github.com/snsten/Klein/blob/main/BOM/ibom.html).

Jumpers

**Note: Only bridge one of these two at a time**, they share same pins route which will change based on closed jumper.

#### Rotary Encoders

If you use MX or Choc choose rotary encoder based on the height:

- For MX with MT3/SA profile you can use the encoder specified in BOM which has an actuator length of 20mm.
- For Choc or MX with medium/low profile keycaps something like EC11N1524402 or similar which have actuator length of 15mm will be better.

This is personal preference so any option is fine.

### Switchplate, Switches and Keycaps

Switchplates are avialable in case directory in [repo](https://github.com/snsten/Klein/tree/main/Case).

Insert few switches in switchplate then gently place it on top of PCB aligning with the hotswap sockets.

Place rest of the switches one by one on switchplate without applying too much force.

After all the switches are placed you can place the keycaps on top of them.

### Case assembly

Case files are available [here](https://github.com/snsten/Klein/tree/main/Case).

### Firmware

The firmware is available [here](https://github.com/snsten/Klein-zmk). Fork the repo and download the firmware zip file from Actions tab in Github.

---

## TODO

&#9744; Add detailed parts list

&#9744; Add images for rest of the steps

&#9744; Add instructions for nice!nano

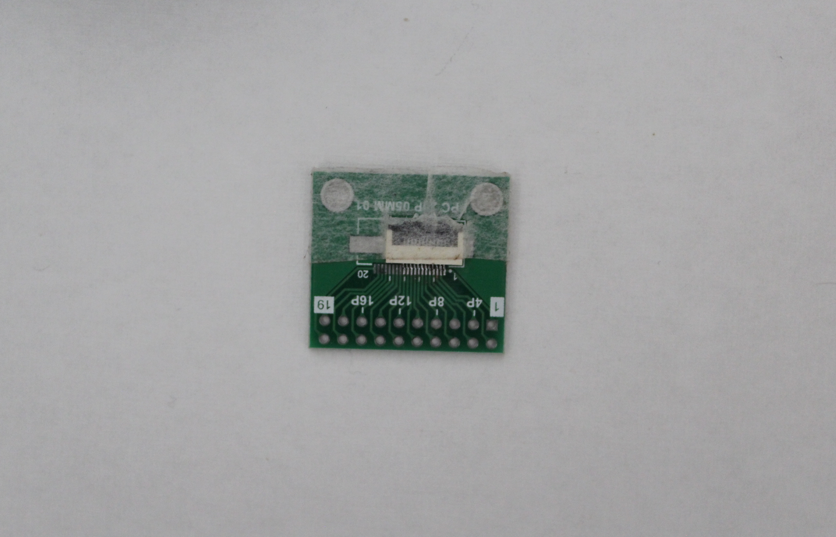
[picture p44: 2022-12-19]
docs/images/buildguide/FPC_Practice.JPG

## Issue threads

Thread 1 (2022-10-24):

CSV of BOM is not in BOM dir

idesignstuff, 2022-10-24:
As a beginner at PCBA orders, I think I'm going to need the CSV of the BOM. Please and thank you!

I'm inspired by how many things you've crammed into this board! Well done!

Closed 2022-10-24.

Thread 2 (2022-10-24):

Case file differences

microfortnight, 2022-10-24:
Really like this board with all the best features from Dilemma, KLOR and others.

Can you point out the differences between the case files?

I understand that the [case-KleinCase.stl](https://github.com/snsten/Klein/blob/main/Case/case-KleinCase.stl) file includes cutouts for USB, TRRS, everything what's needed for the wired version.

Regarding the [case-KleinCase-Wireless.stl](https://github.com/snsten/Klein/blob/main/Case/case-KleinCase-Wireless.stl), might be a dumb question, but it does not seem to have the USB-Connector cutout at the back, isn't this a problem when charging the battery?

What about the temp and 4mm pad file? Thanks in advance!

snsten, 2022-10-25:
Removed extra case files now there's only switchplate, wired and wireless case files.

The usb cutout was removed since if you socket the board like [this](https://www.40percent.club/2018/03/sockets.html) the usb is elevated wrt PCB.
Added the cutout again so that if someone solders the board directly on PCB then the cutout will be required.

microfortnight, 2022-10-25:
Thanks for the clarification 👍

Closed 2022-10-25.

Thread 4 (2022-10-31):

Missing Encoder route in PCB for Pro Micro Controllers

snsten, 2022-10-31:
### Description of Error

- There was a typo in schematics related to Pro Micro Controllers
- ENCA should have been same as ENC_A and ENCB same as ENC_B (can be seen in attached Image)
- It causes the Pro Micro based controllers not be able to use rotary encoder
- XIAO based controllers are not affected due to the additional jumper path

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

### Resoultion of Error
- If you have printed the PCB already and will use wireless version with XIAO, no change is required
- If you plan to use Pro Micro based controller everthing except encoder works
- If you want to use encoder anyway you can connect wires from encoder to pins on Pro Micro

### Summary of Fix
- I have added the routes on PCB and fixed the typo in schematics
- Removed the Gerbers file until I verify the new PCB works (or if someone else try it first)

azhizhinov, 2022-11-02:
Hello.
May I ask you about a firmware, intended to use with your keyboard?
Is that pretty KLOR firmware?
If so, whether this options can be changed from these:
`/* encoder support */
#define ENCODERS_PAD_A       { F5 }
#define ENCODERS_PAD_B       { F4 }
#define ENCODERS_PAD_A_RIGHT { F4 }
#define ENCODERS_PAD_B_RIGHT { F5 }
#define ENCODER_RESOLUTION 2`
To these:
`/* encoder support */
#define ENCODERS_PAD_A       { D1 }
#define ENCODERS_PAD_B       { D0 }
#define ENCODERS_PAD_A_RIGHT { D0 }
#define ENCODERS_PAD_B_RIGHT { D1 }
#define ENCODER_RESOLUTION 2`
Is that will fix the issue for ProMicro-based?
I'm asking, because I've already ordered the PCB. :-)
Thanks for your time.

snsten, 2022-11-02:
Hi, thanks for your interest in this project.

- The firmware used with XIAO-BLE is ZMK. I have a working prototype at [Klein-zmk](https://github.com/snsten/Klein-zmk) repo.
- For Wired version with Pro Micro it will run on QMK.
- I have a test version of QMK with buzzer and touchpad working, yet to be tested are haptics, encoders and trrs connection.
- I will upload the QMK code when I have tested all the features work correctly.

As for the encoder using pin D1 and D0 should work but you will loose the ability to connect OLED or Trackpad if that's fine then you can use them by bridging the jumper JP9 and JP10.

idesignstuff, 2022-11-06:
Planning to use the Xiao BLE for mine. Ordered 10 boards from jlcpcb tonight. Thanks for all the effort to make this!

azhizhinov, 2022-11-06:
Hello.
May I ask you about batteries, you've planned to use?
How the batteries should be attached to the PCBs, that's not covered yet.
Thanks in advance.

snsten, 2022-11-07:
- The battery can be any 3.7V lipo like [these](https://www.lipobattery.us/tag/thickness-3mm/) keeping dimension and capacity in mind.
- Don't get anything with depth 4mm or above as they will be hard to fit.
- I had some with dimensions 26x10x3.5 mm and 200mAh capacity which seem to fit below pcb fine or below microcontroller.

The battery can be placed below PCB, between hotswap sockets and can be secured with some tape.
Placement can be like in the image below (sorry for bad quality).
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

You can connect battery as follows:
- Easiest method is to directly connect battery +- to XIAO pad Bat+,- or nice!nano battery pins bypassing switch.
- Better method is using JST connector B1 (see in ibom) connect battery below PCB then connect BAT+ pin to +pad on XIAO.
- In case of nice!nano it will automatically get +/- pins just connect the battery via JST at B1 like previous step.

Will add build guide soon, feel free to clarify anything and do check the polarity of battery itself and PCB JST pads.

azhizhinov, 2022-11-07:
Hello.
Thanks for your answers.
I think, there is an issue with B1.
Accordingly to KiCAD, it's S2B-PH with 2.0mm pitch, THT.
But, accordingly to your BOM, it's SM02B-GHS-TB(LF)(SN) with 1.25 pitch, SMD.
Thanks for your time.

snsten, 2022-11-07:
You are correct there is a mismatch, since I used Seeed Fusion Open Parts Library [OPL](https://www.seeedstudio.com/opl.html) to get components.
 I couldn't get the 2mm pitch THT connector there it might be there but couldn't find it on that site.
You can solder the 1.25mm connector directly on the pads not ideal but it will work.
I would change the part to more suitable version later created an issue #5.

snsten, 2022-11-13:
> Hello. May I ask you about a firmware, intended to use with your keyboard? Is that pretty KLOR firmware? If so, whether this options can be changed from these: `/* encoder support */ #define ENCODERS_PAD_A { F5 } #define ENCODERS_PAD_B { F4 } #define ENCODERS_PAD_A_RIGHT { F4 } #define ENCODERS_PAD_B_RIGHT { F5 } #define ENCODER_RESOLUTION 2` To these: `/* encoder support */ #define ENCODERS_PAD_A { D1 } #define ENCODERS_PAD_B { D0 } #define ENCODERS_PAD_A_RIGHT { D0 } #define ENCODERS_PAD_B_RIGHT { D1 } #define ENCODER_RESOLUTION 2` Is that will fix the issue for ProMicro-based? I'm asking, because I've already ordered the PCB. :-) Thanks for your time.

Added initial QMK config [here](https://github.com/snsten/qmk_firmware) will add a better keymap and config for RP2040 based boards like KB2040 later.

snsten, 2022-12-24:
PCB with fixed routes works correctly.

Closed 2022-12-24.

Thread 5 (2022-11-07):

Choose suitable component for B1 in BOM

snsten, 2022-11-07:
There is a mismatch between part B1 specified in:

- **PCB** as S2B-PH with 2.0mm pitch, THT
- **BOM** as SM02B-GHS-TB(LF)(SN) with 1.25 pitch, SMD

snsten, 2022-11-18:
Changed part **B1**  to **S2B-PH-K-S(LF)(SN)** in BOM.

Closed 2022-11-18.

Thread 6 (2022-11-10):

OLED i2c pinout mislabeled or misrouted

idesignstuff, 2022-11-10:
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
In my (very limited) experience with PCB design, the square pad = GND and the pinout for a OLED on Amazon appears to have the GND pin in the first position.
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
My hypothesis is that the Silkscreen just needs to match the pinout.

snsten, 2022-11-11:
Don't follow the silkscreen for the old PCB gerbers, for both L and R the order is SDA SCL VCC GND
Fixed the silkscreen labels in the latest commit, the routing is fine just have to bridge the appropriate jumpers for L/R sides.

On R side the GND will be the square pad
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

On L side SDA will be the square pad due to flipping of PCB.
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

idesignstuff, 2022-11-11:
Boards were shipped this week, so I'll roll with it.

idesignstuff, 2023-01-20:
So, I'm hoping to get an OLED on the left (peripheral) side. The first rev PCB's I'm using have no VCC voltage on the left side OLED pins, but it's there on the touchpad pins.
As the OLED mounts upside down, the pins are all wrong according to the silk on the left side.
they would need to be in the same arrangement (SDA,SCL,VCC,GND) on the keys side of the left board, just like they are on the keys side of the righthand board. As you have a set of jumpers for each side, this looks possible, but I haven't learned kicad yet to check...
As a bit of encouragement, I'm typing this on my Klein build!

Closed 2022-11-11.

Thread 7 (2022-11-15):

Clearance of diodes and choc sockets

AlexBaldwin42, 2022-11-15:
On the outside column while using the SOD123 diodes they interfere with the choc sockets.  Still usable by soldering the diodes offset down about a millimeter.

snsten, 2022-11-15:
Can you check if having diodes and switches on the same side and sockets at the other side of PCB have this issue as shown in the attached image. I have not tested with a complete choc build but I think it should work.

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

AlexBaldwin42, 2022-11-16:
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
Here is the clearance i was talking about.

There are no clearance issues with the switches when the diodes are mounted to the opposite side so thats a solution.

snsten, 2022-11-18:
I was aware of this issue that's why I had reversible diodes footprint, keeping the issue open might change the position of the diode in next revision.

P.S. White PCB looks great.

snsten, 2023-01-03:
> Can you check if having diodes and switches on the same side and sockets at the other side of PCB have this issue as shown in the attached image. I have not tested with a complete choc build but I think it should work.
>
> 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

Issue with using diode on top was that it interfered with the switchplate in case of choc build.
Fixed the diode placement in the latest commit.

Closed 2023-01-03.

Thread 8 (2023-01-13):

Debug

LonFas, 2023-01-13:
Good afternoon.
I soldered all for a wired connection, flashed the ProMicro power supply this firmware https://github.com/snsten/Klein-qmk, but any my press the keys doesn't recognized.
Are there any points to check for a closure? May be need connect OLED for debug?

````shell
Jan 14 02:22:08 leviathan.lonfas.lab kernel: usb 1-8: USB disconnect, device number 54
Jan 14 02:22:12 leviathan.lonfas.lab kernel: usb 1-8: new full-speed USB device number 55 using xhci_hcd
Jan 14 02:22:12 leviathan.lonfas.lab kernel: usb 1-8: New USB device found, idVendor=feed, idProduct=0000, bcdDevice= 1.00
Jan 14 02:22:12 leviathan.lonfas.lab kernel: usb 1-8: New USB device strings: Mfr=1, Product=2, SerialNumber=0
Jan 14 02:22:12 leviathan.lonfas.lab kernel: usb 1-8: Product: klein
Jan 14 02:22:12 leviathan.lonfas.lab kernel: usb 1-8: Manufacturer: ssh
Jan 14 02:22:12 leviathan.lonfas.lab kernel: input: ssh klein as /devices/pci0000:00/0000:00:14.0/usb1/1-8/1-8:1.0/0003:FEED:0000.004E/input/input204
Jan 14 02:22:12 leviathan.lonfas.lab kernel: hid-generic 0003:FEED:0000.004E: input,hidraw2: USB HID v1.11 Keyboard [ssh klein] on usb-0000:00:14.0-8/input0
Jan 14 02:22:12 leviathan.lonfas.lab kernel: input: ssh klein Mouse as /devices/pci0000:00/0000:00:14.0/usb1/1-8/1-8:1.1/0003:FEED:0000.004F/input/input205
Jan 14 02:22:12 leviathan.lonfas.lab kernel: input: ssh klein System Control as /devices/pci0000:00/0000:00:14.0/usb1/1-8/1-8:1.1/0003:FEED:0000.004F/input/input206
Jan 14 02:22:12 leviathan.lonfas.lab kernel: input: ssh klein Consumer Control as /devices/pci0000:00/0000:00:14.0/usb1/1-8/1-8:1.1/0003:FEED:0000.004F/input/input207
Jan 14 02:22:12 leviathan.lonfas.lab kernel: input: ssh klein Keyboard as /devices/pci0000:00/0000:00:14.0/usb1/1-8/1-8:1.1/0003:FEED:0000.004F/input/input208
Jan 14 02:22:12 leviathan.lonfas.lab kernel: hid-generic 0003:FEED:0000.004F: input,hidraw3: USB HID v1.11 Mouse [ssh klein] on usb-0000:00:14.0-8/input1
Jan 14 02:22:12 leviathan.lonfas.lab mtp-probe[20915]: checking bus 1, device 55: "/sys/devices/pci0000:00/0000:00:14.0/usb1/1-8"
Jan 14 02:22:12 leviathan.lonfas.lab mtp-probe[20915]: bus: 1, device: 55 was not an MTP device
Jan 14 02:22:12 leviathan.lonfas.lab systemd-logind[533]: Watching system buttons on /dev/input/event18 (ssh klein Consumer Control)
Jan 14 02:22:12 leviathan.lonfas.lab systemd-logind[533]: Watching system buttons on /dev/input/event17 (ssh klein System Control)
Jan 14 02:22:12 leviathan.lonfas.lab systemd-logind[533]: Watching system buttons on /dev/input/event19 (ssh klein Keyboard)
Jan 14 02:22:12 leviathan.lonfas.lab systemd-logind[533]: Watching system buttons on /dev/input/event15 (ssh klein)
Jan 14 02:22:12 leviathan.lonfas.lab mtp-probe[20942]: checking bus 1, device 55: "/sys/devices/pci0000:00/0000:00:14.0/usb1/1-8"
Jan 14 02:22:12 leviathan.lonfas.lab mtp-probe[20942]: bus: 1, device: 55 was not an MTP device
```

Do I necessary to flash both controllers? Or is one of connected to a computer sufficient?

---

p.s. I can send photos of soldering

LonFas, 2023-01-14:
Perhaps I made a mistake on the firmware steps, and I need to somewhere add a layer separately, but this is not in the instructions?

My steps:
1. Install QMK
2. Clone https://github.com/snsten/qmk_firmware to ~/ (linux os)
3. Clone https://github.com/snsten/Klein-qmk to ~/qmk_firmware/keyboards/klein
4. Run qmk flash -kb klein -km default
5. Reset pins GND and Reset

snsten, 2023-01-14:
Hi, I looked at the pro micro image you shared it seems to be in wrong orientation. You have to solder the pins so it sits usb port side down like shown in build guide image [here](https://raw.githubusercontent.com/snsten/Klein/main/docs/images/buildguide/Trackpad_Mount.JPG) or like [this](https://romly.com/blog_images/gherkin_socketing_promicro/socketing_promicro-07.jpg).

snsten, 2023-01-14:
>p.s. Do I need to flash the second controller? Why is he needed (except than encode or screen), if everything works through the left board?

Yes you have to flash both sides, about needing two pro micro you can read the reason at  [qmk docs](https://github.com/qmk/qmk_firmware/blob/master/docs/feature_split_keyboard.md).
> In the case of a wireless connection, do the split appear as two keyboards and work independently? What about TRRS cable between they?

No, in case of wireless you will see only one keyboard the right side as "klein" which you can use to connect to you device PC/Phone etc. The left hand side will not show in bluetooth connections it will connect to the right hand side.
In wireless configuration no TRRS cable is required.

LonFas, 2023-01-14:
> Hi, I looked at the pro micro image you shared it seems to be in wrong orientation. You have to solder the pins so it sits usb port side down like shown in build guide image [here](https://raw.githubusercontent.com/snsten/Klein/main/docs/images/buildguide/Trackpad_Mount.JPG) or like [this](https://romly.com/blog_images/gherkin_socketing_promicro/socketing_promicro-07.jpg).

> Yes you have to flash both sides, about needing two pro micro you can read the reason at [qmk docs](https://github.com/qmk/qmk_firmware/blob/master/docs/feature_split_keyboard.md).

Hm...Fixed. Status has a bit changed:
Left board lightly blink her leds when i press buttons, but nothing printed. Right side doesn't react. If i connect the usb cable to the right controller, the situation will a mirror.

There is a guess:

- I use 4-pole TRRS cable. How many pins should a TRRS socket have? My has five. Is there an error here? https://imgur.com/a/tfRg7VP
- Do I need to specify in the firmware which controller is the main and which is auxiliary?

I soldered OLED pins. Change at QMK firmware OLED_ENABLE to yes at rules.mk.  Maybe these photos will help to understand where need to look? https://imgur.com/a/Rfb8nt9

p.s. This is my first DIY keyboard

snsten, 2023-01-15:
> I use 4-pole TRRS cable. How many pins should a TRRS socket have? My has five. Is there an error here? https://imgur.com/a/tfRg7VP

The TRRS jack should have 4 pins for each of Tip, Ring1, Ring2, Sleeve. If you have a multimeter you can check if you get continuity of these four connections between the TRRS jack and cable. Otherwise get the Model: PJ-320A TRRS Jack.

> Do I need to specify in the firmware which controller is the main and which is auxiliary?

No need to specify the main. The right side is main and it's already defined in the firmware.

About the LED's replace them with 1N4148W diodes, you can read the suitability of different diode tested at https://www.40percent.club/2016/07/diodes.html

LonFas, 2023-01-17:
I soldered all recommended parts.  For some reason, right split - is leading. If i connect the cable to the left split - i get a mirror QWERTY layout. Is this ok for the default setup, and i need configure in firmware something like [this](https://github.com/qmk/qmk_firmware/blob/master/docs/feature_split_keyboard.md#handedness-by-define)?

Found strange behavior. The keyboard doesn't recognize the order of clicks well (if several buttons are pressed with a period somewhere less than half a second, similar when we check new keyboard by pressing). While I suspect the controller board. I think flash firmware to Xiao BLE

snsten, 2023-01-17:
> I soldered all recommended parts. For some reason, right split - is leading. If i connect the cable to the left split - i get a mirror QWERTY layout. Is this ok for the default setup, and i need configure in firmware something like [this](https://github.com/qmk/qmk_firmware/blob/master/docs/feature_split_keyboard.md#handedness-by-define)?

It's Ok, by default the main side is right hand which connects to the PC via usb. If you want to use the left side as main you can change that in the firmware as mentioned in the qmk link.

> Found strange behavior. The keyboard doesn't recognize the order of clicks well (if several buttons are pressed with a period somewhere less than half a second, similar when we check new keyboard by pressing). While I suspect the controller board. I think flash firmware to Xiao BLE

Some keys are mapped to multiple functions so the error in order could be due to that.
In the [keymap.c](https://github.com/snsten/Klein-qmk/blob/61e426dce58ce546a99520e84cac6a4a74e651bb/keymaps/default/keymap.c#L27) file some of the keys are defined with [mod-tap](https://docs.qmk.fm/#/mod_tap).
For example: LGUI_T(KC_A)  means A when key is tapped and LGUI/win key when held.

LonFas, 2023-01-17:
Thank you. I will deal with controller and firmware.

Closed 2023-01-17.

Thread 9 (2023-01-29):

license and commercial request from keycapsss.com

BenRoe, 2023-01-29:
Hello,
my name is Ben from [Keycapsss.com](https://keycapsss.com).
This is not an issue, but i can't find a way to contact you. Feel free to delete this issue.
I wanna ask you if you allow me to add the Klein PCB to my shop?
If i can support you with some parts. Let me know.

You can contact me via mail hello@keycapsss.com
or Discord `Ben | EU/DE | Keycapsss.com#1469`

Greetings Ben

funkycode, 2024-06-23:
Ben, if you get an approval - Azoteq TP43s you have at your shop would fit the keyboard as a glove ;P

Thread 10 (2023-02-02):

Need more info

LonFas, 2023-02-02:
Please give info about "3 pin slide switch" and "click button" what you used in this  [place](https://github.com/snsten/Klein/blob/main/docs/images/buildguide/Trackpad_Resistor.JPG?raw=true) I can't find compatible.

And how solder the battery correctly in wireless mode? I (at link higher) saw what battery soldered to (+) (-) pins, but at your [instructions](https://github.com/snsten/Klein/blob/main/docs/buildguides/buildguide_wireless.md#battery) everything is somehow less clear.

---

I promise to make an MR, to adding the information that I needed to get a working keyboard :)

snsten, 2023-02-04:
The BOM directory contains all the part information.
The reset switch is https://tech.alpsalpine.com/e/products/detail/SKRTLAE010/ and the power switch is https://tech.alpsalpine.com/e/products/detail/SSAJ110100/

For battery you can solder the battery to +- on the PCB directly or use the JST connector.
I will update battery instructions with images in docs for clarity.

Closed 2023-09-09.

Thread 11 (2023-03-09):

Support more keys

zonetw, 2023-03-09:
If Klein can support 42 keys will be wonderful.
Don't know if this is possible, just want to know.

snsten, 2023-03-12:
It's possible, I had a prototype with 40 keys. Will need I/O expansion as the Xiao doesn't have enough pins to support all the 42 keys + extra features at once. I will try to add it in v2 of the board.
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

rafaelpirolla, 2024-03-05:
Could you drop this one into a branch maybe? It would work fine with pro micro ones... :)

rafaelpirolla, 2024-03-25:
I'm trying to edit it but it's getting hard to find all needed footprints and libraries.

snsten, 2024-03-26:
I'll add the 40 keys version in a new branch.
Agree that finding the needed footprints and libraries can be difficult. Will add custom footprints and libraries used in the project to a separate repo later.

snsten, 2024-03-30:
Added the 40 key version in branch [test-extra-keys](https://github.com/snsten/Klein/tree/test-extra-keys)
Include PCB, case and plates for the new design.
Haven't tested the new design fully so it might have some issues.

rafaelpirolla, 2024-04-02:
Is the encoder still usable, you think?

snsten, 2024-04-04:
Rotary encoder is unaffected and should work correctly. The rotary encoder switch shares the same connection as one of the extra keys added so both will emit the same key output.

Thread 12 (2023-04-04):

Downloadable gerber file for online PCB printing services

finex, 2023-04-04:
Hi, would be possible to include a downloadable gerber file (.zip) for online PCB printing service? It would be very useful. Thank you very much.

admilsonmarques, 2023-05-12:
I'd love that as well

suriaribeiro, 2023-06-02:
BOM, CPL and Gerber zip would be fantastic!

MagedEWilliam, 2023-10-12:
Was any one able to generate a good gerbers?
when i generate the files and test it in pcbway viewer, it looks off like it has no holes in the mounting holes

i use default kicad settings when generating the gerbers:
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
https://www.pcbway.com/project/OnlineGerberViewer.html

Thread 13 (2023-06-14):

Regarding battery

regisksc, 2023-06-14:
Firstly, I apologize for my being so noob on this, but I was wondering what would be the issues of placing a larger capacity 3.7 battery over where the trackpad mount was supposed to go(building wireless ofc). I found some 1800mah batteries that are about 40 by 40 mm and 6mm high. But in your guide you suggest not to surpass 3.5mm. Considering I'll print the case and looks are not the most important, would it work placing such battery on top of the XIAOs?

A second doubt would be how can I send the pcb for manufacturing, could you add an explanation on that in the build guide?

snsten, 2023-07-23:
- The battery suggestion is for when you are placing it between the pcb and case. If it is on top you can use the battery you described.
- Placing on top of XIAO directly might not be a good idea, you can get 2 laser cut acrylic covers and place the battery in between them.
- You can import the project file inside pcb dir in KiCad and export gerbers as explained here https://jlcpcb.com/help/article/16-How-to-generate-Gerber-and-Drill-files-in-KiCad-6
- I have added gerbers in releases for convenience but you can diy. Will add the instructions to build guide soon.

P.S.: [No such thing as a stupid question](https://en.wikipedia.org/wiki/No_such_thing_as_a_stupid_question)

Closed 2023-07-28.

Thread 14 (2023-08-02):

Question: why does the wireless version support only OLED *OR* Encoder?

bncpr, 2023-08-02:
Hi, why does the seeeduino xiao ble only support either OLED or Encoder. Can't both of then be connected on the I2C bus? Is it a matter of firmware limitation?

snsten, 2023-08-06:
Reason for not supporting both OLED and Encoder:
1. Due to the limited number of pins in XIAO
2. Both of these can be connected on the same I2C bus, some implications of using this configuration are:
   - The behaviour will depend on how the rotary encoder is designed
   - The encoder could short the line when in rest, check the datasheet for exact behaviour of your encoder
   - It could also interfere with the I2C bus voltage / oled when in use
   - Overall adding two device to same pins will be undefined behaviour in the firmware so I will suggest avoiding it

You can use something like this adapter circuit [i2c-encoder-mini](https://www.duppa.net/shop/i2c-encoder-mini/) safely but you will have to modify and add support for it in the firmware accordingly.

bncpr, 2023-08-06:
I see. Thanks for the answer.

Closed 2023-08-06.

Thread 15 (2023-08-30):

Doubts on building MX wireless

regisksc, 2023-08-30:
I got [these](https://pt.aliexpress.com/item/1005004507826235.html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) batteries, can I solder it using the JST method that doesn't bypass the power switch? And how should I connect it to the controller? Couldn't comprehend from guide only.

I don't have pins to socket the controller, can I build without them? What would the cons be and how do I do so if it's the case?

Does orientation matter when placing the controller?

Can I build the master side with an oled like [this](https://pt.aliexpress.com/item/32879702750.html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) which I have around?

Could you help me understand how to jumper the components? I'd like to have an onled on the left side and a rotary encoder on the right side, if possible.

snsten, 2023-09-09:
> I got [these](https://pt.aliexpress.com/item/1005004507826235.html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) batteries, can I solder it using the JST method that doesn't bypass the power switch?

Yes
> And how should I connect it to the controller?

Solder a wire from the controller + pad to the pin shown in the image in build guide https://github.com/snsten/Klein/blob/main/docs/images/buildguide/XIAO-PCB-Connection.png

> I don't have pins to socket the controller, can I build without them? What would the cons be and how do I do so if it's the case?

If you are not socketing the biggest con would be the wire for connection of battery to controller needs to be placed carefully and if it gets disconnected then soldering it back will be difficult

> Does orientation matter when placing the controller?

Yes it should be usb type-c up on both sides

> Can I build the master side with an oled like this which I have around?

Yes but it might have some issues, the oled support in wireless using zmk is still not officially supported refer to https://zmk.dev/docs/features/displays

> Could you help me understand how to jumper the components? I'd like to have an onled on the left side and a rotary encoder on the right side, if possible.

For left side oled bridge 4 jumpers marked by "Jumper for L" and for rotary encoder on right side bridge 2 jumpers marked "Jumper ENC". You can refer the build guide for the same https://github.com/snsten/Klein/blob/main/docs/buildguides/buildguide_wireless.md#jumpers

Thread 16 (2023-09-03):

Switch plate too tight for MX switches

suriaribeiro, 2023-09-03:
Hi, the switch plate STL does not work with MX switches because its too tight. Do you maybe have an editable version of the STL file or revised version of the switch plate?

suriaribeiro, 2023-09-05:
Managed to create an alternative one, see PR here https://github.com/snsten/Klein/pull/17

snsten, 2023-09-09:
Hi, I am using MX build with the provided STL and didn't found this issue.
Can you let me know what materials are you using for your 3D print, specific switches you are using or any other info relevant for debugging.

suriaribeiro, 2023-09-09:
Hi, maybe my printer is not doing a decent job. I had to shave a fair bit to fit choc switches. For MX switches it was impossible. For printing the plate I used PLA+ on a Elegoo Neptune 2s. I tried both 0.2 and 0.12 layer heights.

suriaribeiro, 2023-09-09:
obviously I would not be offended if you reject the PR given that no one reported this same issue :)

snsten, 2023-09-10:
Can you try to print any other keyboard's switch plate / case like corne etc. and check if the switch tolerance issue is due to the 3D printer settings or with the file I have in the repo.
If I accept PR without knowing the root cause it will cause confusion for new users on choosing which file to 3D print.

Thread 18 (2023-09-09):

Ideas for a klein v2

suriaribeiro, 2023-09-09:
I absolutely love this keyboard! Immediately my daily driver bringing in a lot of joy.

With that said I have a few suggestions for an eventual 2nd version for an improved version:

1-Add more keys using the nfc pads.
2-Tighter tolerances for the Switches. In my MX and choc switches were very loose making the switchplate a must.
3-Use a Xiao dedicated footprint to make it  easier to solder the bat+-, rst and nfc pads.

For 2 and 3 the totem keyboard might give you some good ideas.

snsten, 2023-09-10:
Thanks, I am glad you like it.
> Use a Xiao dedicated footprint to make it easier to solder the bat+-, rst and nfc pads.

This will be difficult to imlement due to the overlap of pro micro and xiao footprints.

I will keep all of these suggestions in mind for v2.

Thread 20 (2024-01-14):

SwitchPlateFR4 not really a switchplate?

jrsmith3, 2024-01-14:
I would like a switchplate for my Klein made from FR4, but it seems like the KiCAD files in the [`Klein/Case/Prototype/SwitchPlateFR4` directory](https://github.com/snsten/Klein/tree/main/Case/Prototype/SwitchPlateFR4) are the same design as the main Klein PCB (see attached screenshots). Am I missing something?

This keyboard looks great, and I'm excited to start using it.

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

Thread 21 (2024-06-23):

nice nano zmk fw

funkycode, 2024-06-23:
hey, I made [Klein ZMK repo for nicenano ](https://github.com/funkycode/Klein-zmk) - might be useful for someone.
I assume it is possible to have 2 options in same repo, but not sure how to achieve it.

P.S.:
Few notes for future improvements:
1. seems like with nicenano there is barely any place for screen
2. I would suggest to have more pins for touchpad (I think azoteq tp43s is exact dimensions to fit keyboard, and I assume RDY and maybe RST pins would be useful)
3. if it is possible to move encoder a little bit so it would be possible to use 1.5 or even 2u for outter thumb cluster buttons
4. i would suggest to use little bit bigger on/off switch and reset buttone (like on corne wireless) as those were pain to solder manually

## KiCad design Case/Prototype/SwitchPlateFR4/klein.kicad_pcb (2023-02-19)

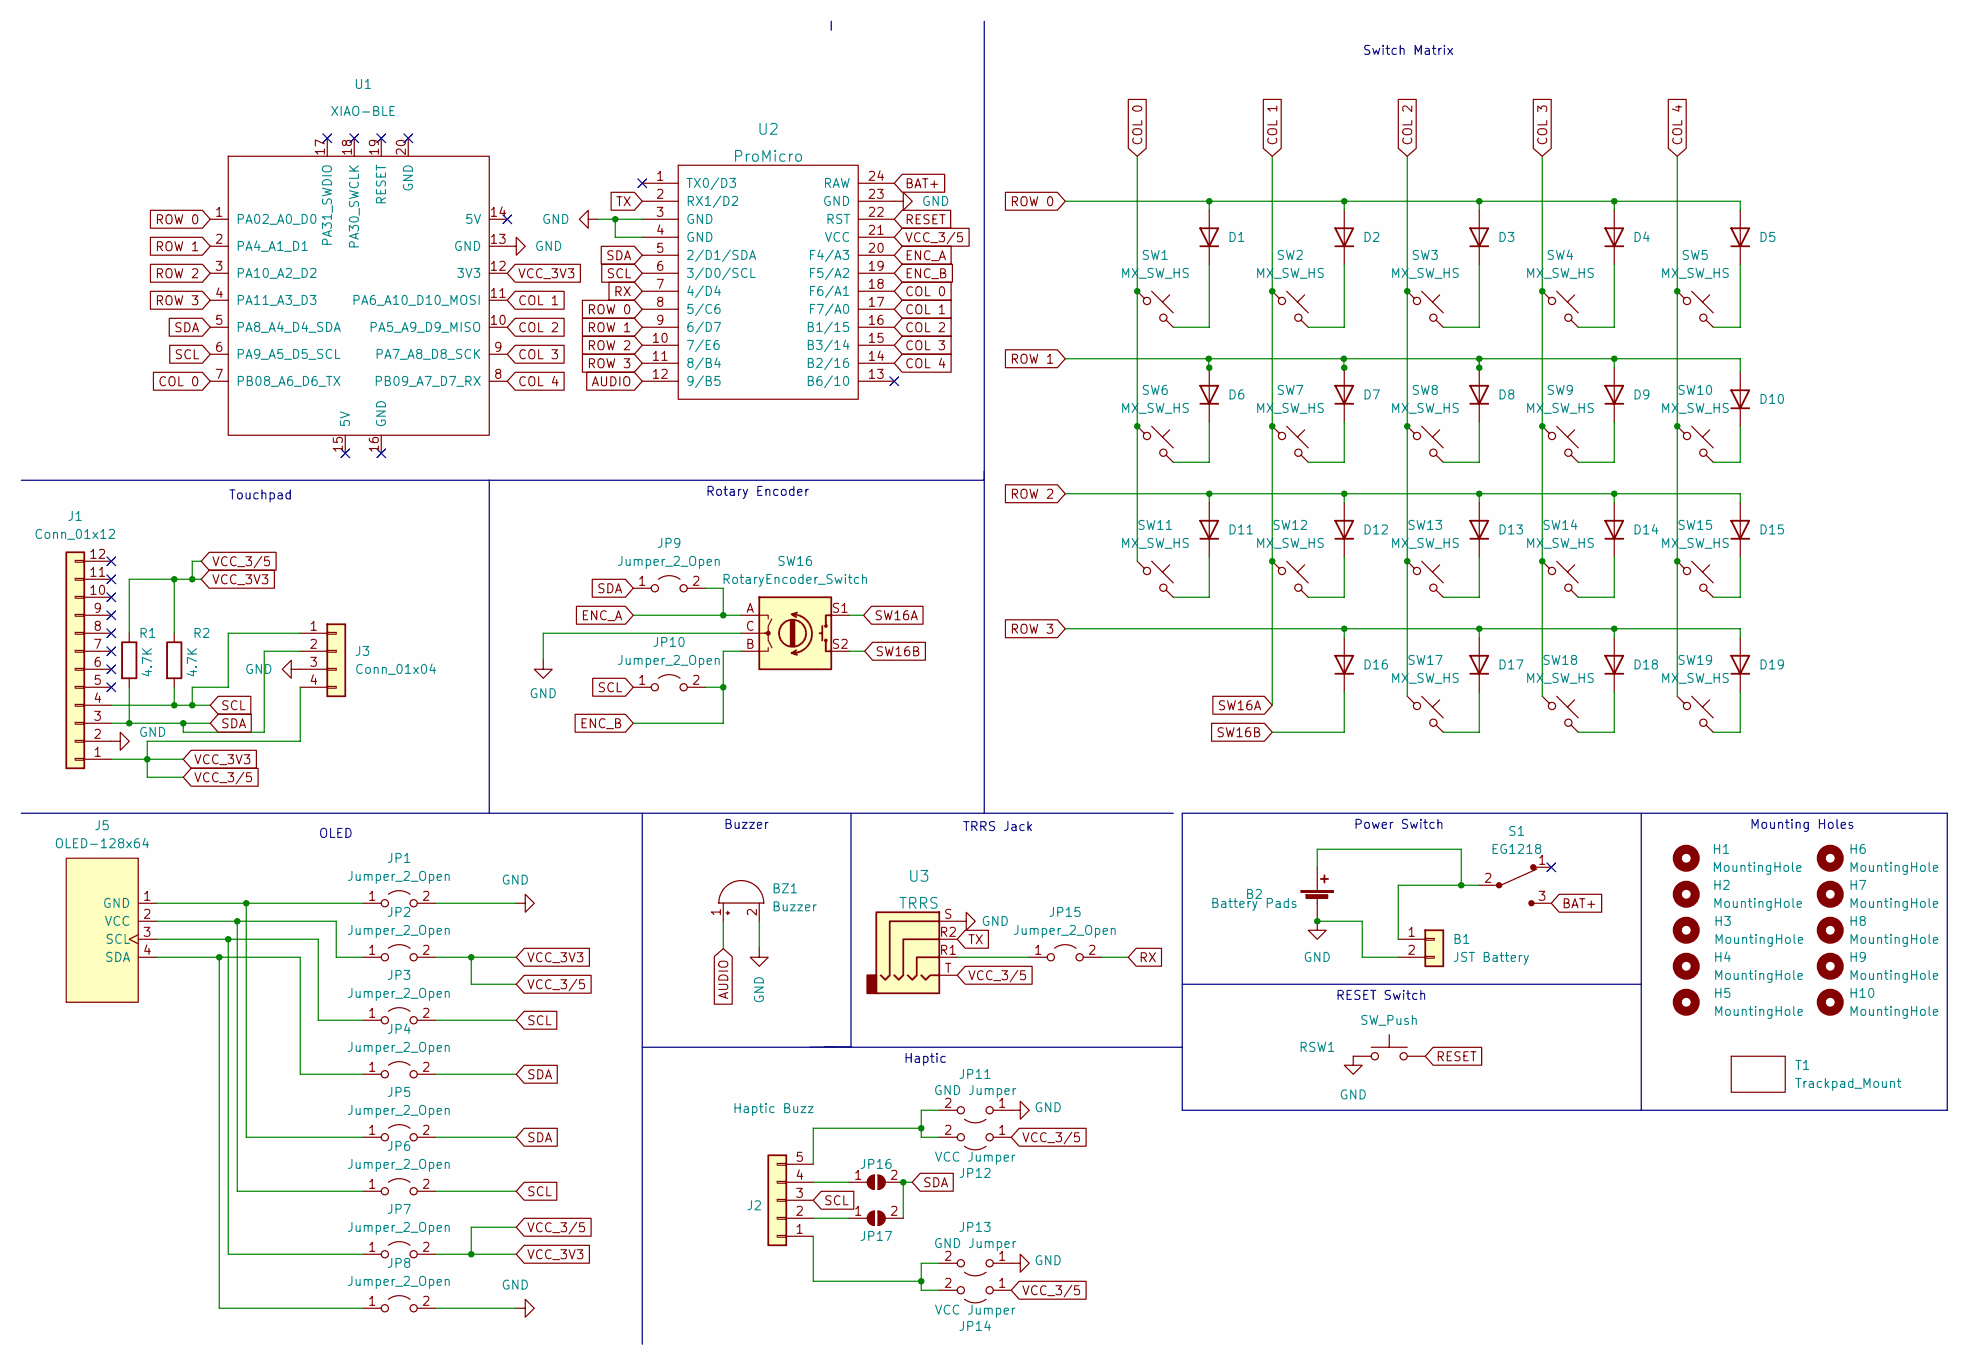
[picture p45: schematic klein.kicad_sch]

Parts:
B1: JST Battery; JST_PH_reversible
B2: Battery Pads; SolderWire-0.5sqmm_1x02_P4.8mm_D0.9mm_OD2.3mm
BZ1: Buzzer; Buzzer_Mallory_AST1109MLTRQ_reversible
D1, D2, D3, D4, D5, D6, D7, D8, D9, D10, D11, D12, D13, D14, D15, D16, D17, D18, D19: DIODE; D3_TH_SMD
H1, H2, H4, H5, H6, H8: MountingHole; MountingHole_3.2mm_M3_ISO7380_Pad
H3: MountingHole; MountingHole_3.2mm_M3
H7: MountingHole; MountingHole_2.2mm_M2
H9, H10: MountingHole; MountingHole_2.2mm_M2_ISO7380_Pad
J1: Conn_01x12; Hirose_FH12-12S-0.5SH_1x12-1MP_P0.50mm_Horizontal
J2: Haptic Buzz; Pimoroni Haptic Buzz DRV2605L Driver
J3: Conn_01x04; SolderWire-0.1sqmm_1x04_P3.6mm_D0.4mm_OD1mm
J5: OLED-128x64
JP1, JP2, JP3, JP4, JP5, JP6, JP7, JP8, JP15: Jumper_2_Open; SolderJumper-2_P1.3mm_Open_RoundedPad1.0x1.5mm
JP9, JP10: Jumper_2_Open; SolderJumper-2_P1.3mm_Open_Pad1.0x1.5mm
JP11, JP13: GND Jumper; SolderJumper-2_P1.3mm_Open_Pad1.0x1.5mm
JP12, JP14: VCC Jumper; SolderJumper-2_P1.3mm_Open_Pad1.0x1.5mm
JP16, JP17: SolderJumper_2_Open; SolderJumper-2_P1.3mm_Open_Pad1.0x1.5mm
R1, R2: 4.7K; RESISTOR
RSW1: SW_Push; SW_Push_1P1T-MP_NO_Horizontal_Alps_SKRTLAE010_both_sides
S1: EG1218; RevSlideSwitch; MPN EG1218; Digi-Key_PN EG1903-ND
SW1, SW2, SW3, SW4, SW5, SW6, SW7, SW8, SW9, SW10, SW11, SW12, SW13, SW14, SW15, SW17, SW18, SW19: MX_SW_HS; MX_Choc_Hotswap_Mod
SW16: RotaryEncoder_Switch; MX-1U-EC11_Switch
T1: Trackpad_Mount; Trackpad Mount
U1: XIAO-BLE
U2: ProMicro; ProMicro_rev2
U3: TRRS; MJ-4PP-9

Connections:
AUDIO: BZ1.1 (-), U2.12 (9/B5)
BAT+: S1.3, U2.24 (RAW)
COL 0: SW1.1, SW6.1, SW11.1, U1.7 (PB08_A6_D6_TX), U2.18 (F6/A1)
COL 1: SW2.1, SW7.1, SW12.1, SW16.S1, U1.11 (PA6_A10_D10_MOSI), U2.17 (F7/A0)
COL 2: SW3.1, SW8.1, SW13.1, SW17.1, U1.10 (PA5_A9_D9_MISO), U2.16 (B1/15)
COL 3: SW4.1, SW9.1, SW14.1, SW18.1, U1.9 (PA7_A8_D8_SCK), U2.15 (B3/14)
COL 4: SW5.1, SW10.1, SW15.1, SW19.1, U1.8 (PB09_A7_D7_RX), U2.14 (B2/16)
ENC_A: JP9.2 (B), SW16.A, U2.20 (F4/A3)
ENC_B: JP10.2 (B), SW16.B, U2.19 (F5/A2)
GND: B1.2, B2.2 (-), BZ1.2 (+), J1.2, J3.3, JP1.2 (B), JP8.2 (B), JP11.1 (A), JP13.1 (A), RSW1.1, SW16.C, U1.13 (GND), U2.3 (GND), U2.4 (GND), U2.23 (GND), U3.S
unnamed: B1.1, B2.1 (+), S1.2
unnamed: D1.1 (K), SW1.2
unnamed: D2.1 (K), SW2.2
unnamed: D3.1 (K), SW3.2
unnamed: D4.1 (K), SW4.2
unnamed: D5.1 (K), SW5.2
unnamed: D6.1 (K), SW6.2
unnamed: D7.1 (K), SW7.2
unnamed: D8.1 (K), SW8.2
unnamed: D9.1 (K), SW9.2
unnamed: D10.1 (K), SW10.2
unnamed: D11.1 (K), SW11.2
unnamed: D12.1 (K), SW12.2
unnamed: D13.1 (K), SW13.2
unnamed: D14.1 (K), SW14.2
unnamed: D15.1 (K), SW15.2
unnamed: D17.1 (K), SW17.2
unnamed: D18.1 (K), SW18.2
unnamed: D19.1 (K), SW19.2
unnamed: J2.1, JP13.2 (B), JP14.2 (B)
unnamed: J2.2, JP17.1 (A)
unnamed: J2.4, JP16.1 (A)
unnamed: J2.5, JP11.2 (B), JP12.2 (B)
unnamed: J5.1 (GND), JP1.1 (A), JP5.1 (A)
unnamed: J5.2 (VCC), JP2.1 (A), JP6.1 (A)
unnamed: J5.3 (SCL), JP3.1 (A), JP7.1 (A)
unnamed: J5.4 (SDA), JP4.1 (A), JP8.1 (A)
unnamed: JP15.1 (A), U3.R1
RESET: RSW1.2, U2.22 (RST)
ROW 0: D1.2 (A), D2.2 (A), D3.2 (A), D4.2 (A), D5.2 (A), U1.1 (PA02_A0_D0), U2.8 (5/C6)
ROW 1: D6.2 (A), D7.2 (A), D8.2 (A), D9.2 (A), D10.2 (A), U1.2 (PA4_A1_D1), U2.9 (6/D7)
ROW 2: D11.2 (A), D12.2 (A), D13.2 (A), D14.2 (A), D15.2 (A), U1.3 (PA10_A2_D2), U2.10 (7/E6)
ROW 3: D16.2 (A), D17.2 (A), D18.2 (A), D19.2 (A), U1.4 (PA11_A3_D3), U2.11 (8/B4)
RX: JP15.2 (B), U2.7 (4/D4)
SCL: J1.4, J2.3, J3.1, JP3.2 (B), JP6.2 (B), JP10.1 (A), R2.2, U1.6 (PA9_A5_D5_SCL), U2.6 (3/D0/SCL)
SDA: J1.3, J3.2, JP4.2 (B), JP5.2 (B), JP9.1 (A), JP16.2 (B), JP17.2 (B), R1.2, U1.5 (PA8_A4_D4_SDA), U2.5 (2/D1/SDA)
SW16B: D16.1 (K), SW16.S2
TX: U2.2 (RX1/D2), U3.R2
VCC_3V3: J1.1, J3.4, JP2.2 (B), JP7.2 (B), JP12.1 (A), JP14.1 (A), R1.1, R2.1, U1.12 (3V3), U2.21 (VCC), U3.T

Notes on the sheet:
Switch Matrix
OLED
Rotary Encoder
Touchpad
Haptic
Power Switch
Buzzer
TRRS Jack
RESET Switch
Mounting Holes

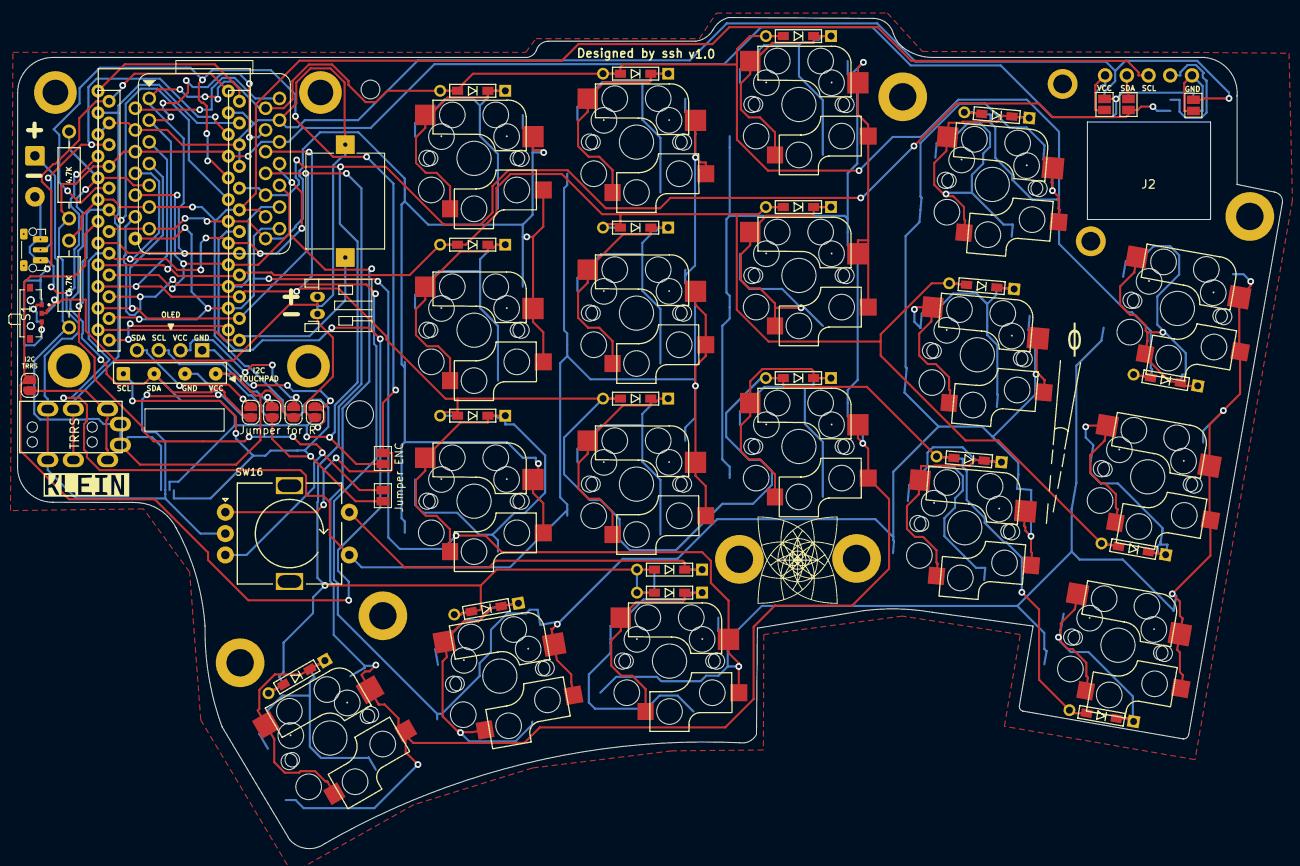
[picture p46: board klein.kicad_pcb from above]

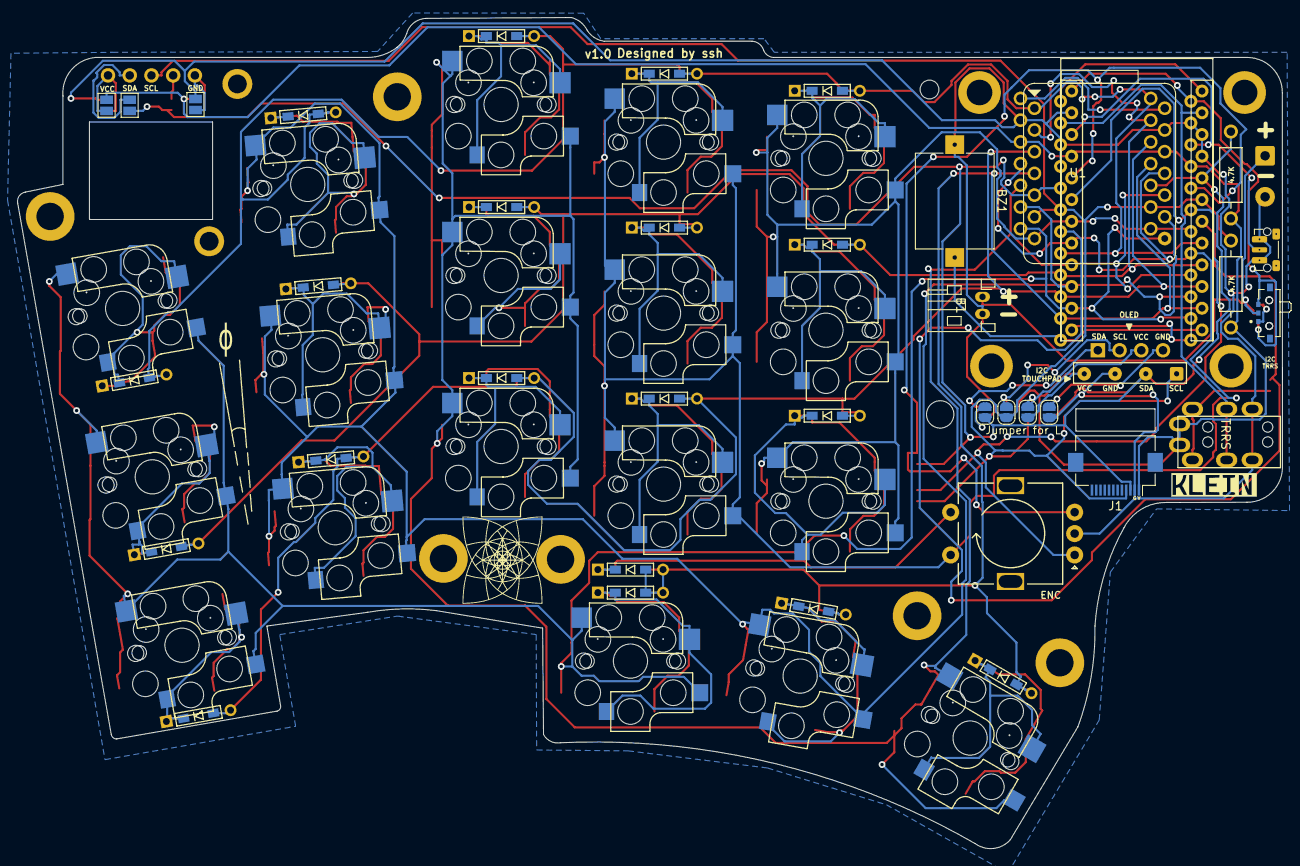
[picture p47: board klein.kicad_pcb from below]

Board: 2 copper layers, 147.9 x 97.2 mm, 84 parts (49 on the bottom side), 49 nets.

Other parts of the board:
G3, G4: LOGO; klein
G33, G34: LOGO; klein_small

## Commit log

2022-10-24 Added BOM csv file
    [BOM-3235-SEEED.csv]
2022-10-24 Update BOM-3235-SEEED.csv
    Changed "RS1" to "RSW1" to match the interactive BOM.
    [BOM-3235-SEEED.csv]
2022-10-25 Updated case files
    [Klein-switchplate.stl, KleinCaseR-wired.stl, KleinCaseR-wireless.stl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]
2022-10-31 Fix PCB Encoder Routes (Typo in Schematic) and IBOM project name fix
    [klein.kicad_pcb, klein.kicad_sch]
2022-10-31 Removed Gerbers due to missing router for Encoders in Pro Micro based controllers
2022-11-10 Fix OLED silk screen text
    [klein.kicad_pcb]
2022-11-18 Fix JST battery connector B1 part difference in BOM and PCB
    [BOM-3235-SEEED.csv]
2022-11-19 Added FreeCad Case design files
    [Wired_Prototype.FCStd]
2022-11-20 Added initial wireless build guide
2022-11-20 Minor change in wireless build guide and Readme
2022-11-20 Added battery info in wireless build guide
2022-12-19 Wired build guide added
2022-12-19 Fix firmware link in wired build guide
2022-12-19 Updated case design with better fit, support structures and initial trackpad mount design
    [KleinCase-R.stl, KleinCaseR-wired.stl, KleinCaseR-wireless.stl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]
2022-12-24 Fix diode clearance on last column
2023-01-07 Added wired build guide link in readme
2023-02-19 Removed TRRS jumper
    [klein.kicad_sch]
2023-02-19 Added Switchplate PCB files and updated readme
    [klein.kicad_pcb, klein.kicad_sch]
2023-07-23 Added XIAO Cover Plate
    Useful for laser cutting acrylic cover for xiao and an alternative to the 3d printed cover
    [coverPlate.dxf]
